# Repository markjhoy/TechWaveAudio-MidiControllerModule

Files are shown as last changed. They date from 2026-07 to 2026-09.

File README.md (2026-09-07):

# [TechWave Audio MIDI to CV Module](https://techwaveaudio.com/techwave-audio-mcm-100-midi-to-cv-eurorack-module/) : MCM-100

A monophonic MIDI controller Eurorack module using the Raspberry Pi Pico (RP2040).

Brought to you by [TechWave Audio](https://techwaveaudio.com)

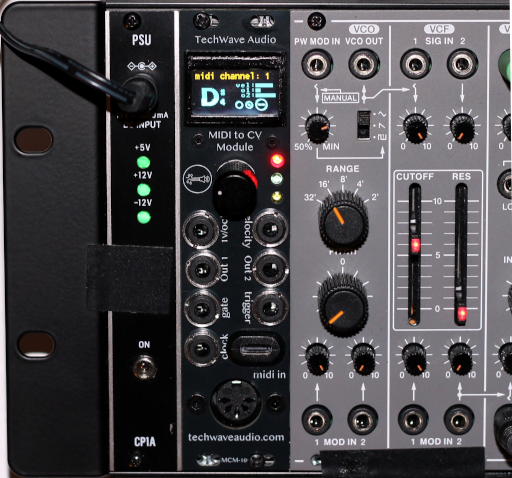
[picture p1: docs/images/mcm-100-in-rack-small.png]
TechWave Audio Midi Controller Module


## Features
* Single or omni MIDI channel input
* MIDI input via class-compliant USB-C or standard 5-pin MIDI cable
* Four CV outputs for note (1v/oct), Velocity, assignable Out 1 and Out 2 
  * 1v/octave through 10 octaves (at 0 to +10v), or 5 octaves (at 0 to +5v)
  * Two CV outputs with flexible routing
  * All CV outputs voltage selectable from 0v to +10v or 0 to +5v
* Expandable with additional four flexible-routed CV outputs.
* Gate, trigger, and clock full 0 to +5v outputs with divisible clock sync ticks
* Selectable note priority (last, highest, lowest)
* Tuneable pitch and velocity adjust
* Customizable trigger output duration pulse width
* Pitch bend response range from 0 to 5 octaves
* Real time display of note and output states
* Settings persist to on-board flash ROM
* 6hp wide, 3U height
* Max Power Draw:
  * +12v: 72mA (80mA with expansion) 
  * -12v: 15mA (20mA with expansion)
  * +5v: 0mA

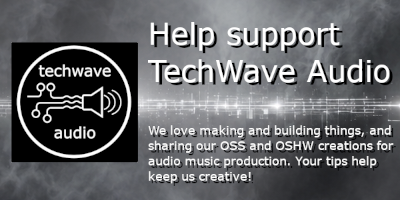
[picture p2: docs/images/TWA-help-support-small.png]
Help support our work!
[](https://ko-fi.com/techwaveaudio)

---

### Responds to the following MIDI messages:

* **Note on / off**: sends/stops the note and velocity outputs.
  * Sends a trigger pulse on note on, and turns on the gate for the duration of the note.
  * For +10v output, responds to C-1 (note number 0) to B9 (note number 119).
  * For +5v output, responds to C2 (middle-C, note number 36) to B6 (note number 95).
* **Volume**: increases or decreases the velocity output.
* **Pitch bend**: modifies any currently playing note. Adjustable range from 0 to 5 octaves. 
* **Sustain**: holds a note on while the sustain is active.
* **Aftertouch**: selectable as an aux and/or control output.
* **Expression**: selectable as an aux and/or control output.
* **Mod wheel**: selectable as an aux and/or control output.
* **Effect 1**: selectable as an aux and/or control output.
* **Effect 2**: selectable as an aux and/or control output.
* **Start** and **Continue** sequence: selectable as an aux and/or control output.
* **Stop** sequence: selectable as an aux and/or control output.
* **Mute** (all notes off): clears any note, velocity, and gate outputs.
* **Clock tick**: MIDI clock ticks are sent directly to the `Clock` output and can be routed as an aux and/or control output.
* **Reset**: reset the MIDI input messaging queue and stops any output.

---

### Inputs

* **MIDI in**: single channel or respond to all channels (omni)
  * Both MIDI via UART and USB MIDI device in (as of v1.2.0) 
* **Menu navigation**: Five way switch (up/down, left/right, push enter)

--- 
### Outputs

* Four CV outputs:
  * **Note**: 0 to 10v output (selectable to 0 to 5v) for CV with 1v per octave.
  * **Velocity**: 0 to 10v output (selectable to 0 to 5v) for velocity / volume
  * **Out 1**: customizable CV output (0v to +10v max, selectable to 0v to +5v)
  * **Out 2**: customizable CV output (0v to +10v max, selectable to 0v to +5v)
* **Trigger**: single pulse when a note turns on, with customizable pulse on time (high / low level output)
* **Gate**: signal goes high while a note is on (high / low level output)
* **Clock**: 1ms pulse with each MIDI clock tick (high / low level output). Selectable to various clock divisions.

Using the MCM-100-EX Expansion Module, you can also add an additional four assignable CV outputs.

---

### Power

This module requires a full 16 pin (2x08 connector) standard Eurorack power connection as it uses both +/- 12v lines as well as the +5v source. 
Optional selectors in the hardware (via a DIP switch) allow the note signal to pass through to the CV bus line, and the gate signal as well.

Be certain when you plug the connector in that the orientation is the correct way, with the -12v line on the bottom (usually with the red stripe).

---

## Usage

On startup, you should see the boot screen with the current version:

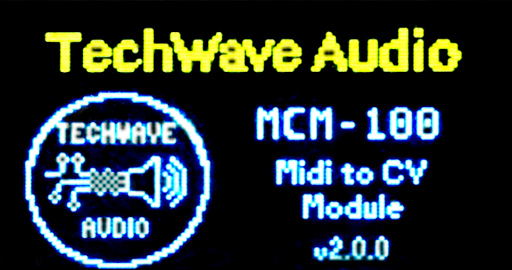
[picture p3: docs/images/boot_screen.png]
starting boot screen


The note and clock LEDs should turn on and off a few times before the dashboard screen is shown and the module is ready to be used.

The user manual can be found on the [TechWave Audio website](https://techwaveaudio.com/support/manuals/MCM-100-User_Manual.pdf).

### Dashboard

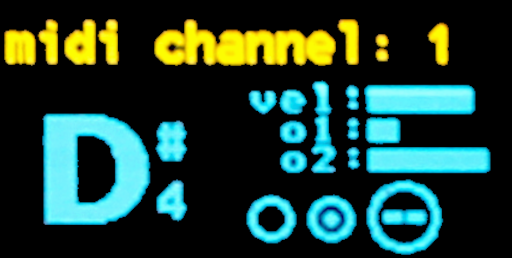
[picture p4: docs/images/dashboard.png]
main dashboard display


The dashboard shows the status of the current MIDI channel that it is listening on, as well as various outputs:
* The note and octave
* `vel`: The current velocity (corresponding to 0v to +10/+5v)
* `o1`: The current Out 1 value (corresponding to 0v to +10/+5v)
* `o2`: The current Out 2 value (corresponding to 0v to +10/+5v)
* Indicators for the state of the trigger, gate, and clock

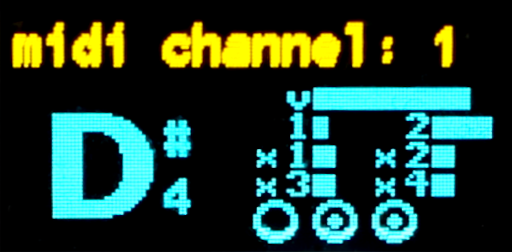
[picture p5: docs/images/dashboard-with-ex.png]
dashboard with expansion


If the MCM-100-EX expansion module is attached, additionally it will show:
* `x1`: The current Out X1 value (corresponding to 0v to +10/+5v)
* `x2`: The current Out X2 value (corresponding to 0v to +10/+5v)
* `x3`: The current Out X3 value (corresponding to 0v to +10/+5v)
* `x4`: The current Out X4 value (corresponding to 0v to +10/+5v)

While using the module, you can turn the dashboard display on and off via the display settings menu.
You can also adjust how often the display refreshes (set to a longer time if display events start to get dropped, shorter time for more frequent updates).

### Settings Menu

There are numerous settings available from the settings menu.
Pressing the encoder button on the dashboard display (regardless if the display is visible or not) will enter the menu.
See the [Menu System](./docs/MENU_SYSTEM.md) documentation for the menu system details.

**Note**: any settings are not persisted until you exit the menu back to the dashboard (with the exception of when resetting the settings to default).

## Building the Firmware From Source

### Prerequisites

* [Raspberry Pi Pico SDK](https://github.com/raspberrypi/pico-sdk)
* CMake
* Your favourite C++ compiler
* A compatible toolchain for building Pico firmware

### Setup

1. Initialize the Git submodules:
   1. run: `git submodule init`
   2. run: `git submodule update`
2. Copy the `.env.cmake.sample` to `.env.cmake`
3. Edit your `.env.cmake` for the following variables:
```
PICO_SDK_PATH {the path to the PICO_SDK directory)
PICO_TOOLCHAIN_PATH (path to the pico toolchain for your build machine)

# You should _not_ have to change the following
set(PICO_PLATFORM rp2040)
set(PICO_BOARD pico)
```

### Build script
```
./build.sh
```

This will run the full clean and build.

The firmware file will be put in:
```
./dist/TechWaveAudio-MCM-v2.0.0.uf2
```

## Firmware Updates

For this, you'll need a [firmware release](https://github.com/TechWave-Audio/TechWaveAudio-MidiControllerModule/releases) (or build your on locally), as well as a USB cable that has a micro-usb port on one end.

1.	Power off your rack.
2.	Remove the module from your rack but keep the module plugged in via the power cable.
3.	Download the desired firmware file version from the GitHub repository [firmware release](https://github.com/TechWave-Audio/TechWaveAudio-MidiControllerModule/releases). You only need to download the file with the .uf2 extension.
4.	Plug your USB-C cable into the jack on the front of the module and the other end into the computer with the firmware.
5.	While holding down the small boot select (BOOTSEL) button on the board, power on the module. Keep holding the boot select button until the module appears on your computer. The on-board Raspberry Pi Pico board will appear as a mass storage device, usually named “RPI-RP2”
6.	Copy the downloaded firmware .uf2 file to the storage device. When complete, the module should reboot.
7.	Power off your rack again.
8.	Disconnect your USB cable from the module and your computer. Your computer may give you a warning about the device not being properly ejected. You can safely ignore this warning.
9.	Put the module back into your rack and power back on.

Note that any settings you many have modified will be reset to any default.

## Design

## Schematic, PCB, and hardware

See the [hardware design](./docs/HARDWARE_DESIGN.md) documentation for information on the schematic and PCB design for the module.

Note - all files provided including KiCad designs and any gerber files are provided as-is and to be used at your own risk.
TechWave Audio does not guarantee the accuracy or any correctness of these files.
See the [HW_LICENSE license file](./HW_LICENSE.txt) for more, specifically the section "6 DISCLAIMER AND LIABILITY".

## Licensing

Software in this repository is licensed under the [BSD-3 License](LICENSE.txt). By using or contributing content to this repository you are agreeing to place your contributions under this license.

Hardware designs for this repository are [licensed under the CERN-OHL-S](HW_LICENSE.txt) ([CERN Open Hardware License](https://cern-ohl.web.cern.ch/)).

Parts of this repository may reference, depend on, or use compiled third party libraries. See [NOTICE.txt](NOTICE.txt) for additional details.

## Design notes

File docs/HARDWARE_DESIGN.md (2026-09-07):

# TechWave Audio Midi Controller Module Hardware Design

Simply put, the module reads MIDI messages in, and outputs signals to digital analog controllers to provide the voltage outputs.
This is all based around a RP2040 microcontroller as the brains for handling inputs and outputs.

* [Main Board](#main-board)
  * [Microcontroller](#microcontroller)
  * [MIDI Input](#midi-input)
  * [Note, Velocity, and Out 1 and 2 DAC](#note-velocity-and-out-1-and-2-dac)
  * [Encoder Button Debounce](#encoder-button-debouncing)
  * [Power](#power)
  * [Expansion Header](#expansion-header)

* [I/O Board](#io-board)
  * [Note, Velocity, Out 1 and 2 Outputs](#note-velocity-out-1-and-2-outputs)
  * [Gate, Trigger, and Clock Output](#gate-trigger-and-clock-output)
  * [Rotary Encoder User Input](#rotary-encoder-user-input)
  * [OLED Screen](#oled-screen)
  
* [MCM-100-EX Expansion Module](#mcm-100-ex-expansion-module)

* [MCM-100 Parts List / BOM](#mcm-100-parts-list)
* [MCM-100-EX Parts List / BOM](#mcm-100-ex-parts-list)
* [Board Renderings](#board-renderings)

# Main Board

The main board (lower PCB) houses the RP2040 Raspberry Pi Pico microcontroller, MIDI input, the note, velocity, and out 1 and 2 DAC, and power handling. 

## Microcontroller
The microcontroller at the heart of the system is a RP2040 based [Raspberry Pi Pico 1](https://www.raspberrypi.com/documentation/microcontrollers/pico-series.html#pico1).
The RP2040 is a very capable and low cost with enough GPIO, I2C, and SPI lines to handle the needs of this system.

To keep the design a bit more accessible, I made the conscience decision to use the Raspberry Pi Pico module itself instead of opting for using a discrete RP2040 chip only.
Using a discrete RP2040 itself would have allowed for a much smaller footprint on the PCB, however the using the full module allowed for easier testing overall without having to worry about getting the microcontroller section of the circuitry right (why reinvent the wheel).
It also makes flashing the firmware much easier (although I could have added a discrete USB port for doing so).

Both cores of the RP2040 are used. Core 0 handles the display, buttons, menus, and state. 
Core 1 handles the MIDI input and hardware outputs.

## MIDI Input

The MIDI input from the 5-pin DIN MIDI cable jack is handled by a 6N137 optocoupler that signals at +5v.
The output signal is reduced to +3.3v via a simple voltage divider to bring the signal to a manageable level for the microcontroller to use.
COnversely, the USB-C jack is soldered directly into the data + and -, and the ground for the USB on the Pi Pico.
All processing of the signal happens within the software.

## Note, Velocity, and Out 1 and 2 DAC

The module uses a DAC7554 quad 12-bit SPI digital to analog IC for its CV output.
The Pi Pico communicates with the IC, and the resulting 0 to +5v signal is passed to the I/O board where the op amps provide additional gain and trimming.

## Encoder Button Debouncing

On the main board as well, there is a small circuit consisting of several filtering capacitors and resistors along with a NPN transistor that acts as a light hardware debounce for the rotary encoder button.
This arrangements provides for approximately a 40ms debounce of the encoder button.

## Power

The power coupling for the module uses a standard 10 pin (2x05) IDC connector as detailed in the original [A-100 Doepfer power system bus](https://doepfer.de/a100_man/a100t_e.htm).

There are a pair of schottky diodes for reverse power protection as well as several capacitors for power filtering.
A 7805 equivalent power regulator is used to drop the +12v line down to +5v for input to the microcontroller, DAC, optocoupler, and encoder button debouncing.

As measured, the maximum power draw is:
* +12v: 72mA (80mA with expansion)
* -12v: 15mA (20mA with expansion)
* +5v: 0mA

## Expansion Header

The expansion header is a 2x05 set of pin headers that the MCM-100-EX expansion cable attaches to.
The headers carry +12v/-12v/+5v power as well as SPI lines for communicating with the DAC on the expansion board.

# I/O Board

The upper I/O board contains the output jacks, the screen, rotary encoder as well as op amp gain and trimmer 

## Note, Velocity, Out 1 and 2 Outputs

The note 1v/oct and velocity signals are handled by two MCP4725 DAC ICs.
These are single channel, 12 bit DAC chips that use I2C for communication from the microcontroller.
Since these chips are able to output between 0 and +5v, the signal is then increased to the 0 to +10v range via a TL074 opamp.
Additional 1k trimming potentiometers are used to fine tune the output.

The control and aux signals are handled by a single MCP4902 DAC IC.
This is a single channel 8 bit DAC chip that uses SPI for communication with the microcontroller.
This chip produces a stable output voltage from 0 to +5v, which in turns is sent through a TL074 op amp to increase the range to 0 to +10v.
Like the note and velocity outputs, there are 1k trim potentiometers to fine tune the output voltages.

## Gate, Trigger, and Clock Output

The gate, trigger and clock signals all run directly from the associated GPIO pins from the microcontroller.
Because these signals coming out of the Pi Pico are at 3.3v, a TL074 op amp is used to turn the pulses into 0 to +5v signals.

## Rotary Encoder User Input

The rotary encoder is a standard EC11 rotary encoder.
To attach the rotary encoder to the I/O board, a custom mid-board was created.
See [the design files for the custom board](../design/RotaryEncoderCarrierBoard) in the design folder.

## OLED Screen

The OLED screen used is a 0.96" display using the SSD1306 chipset.
These modules can be found at a reasonable price, and offer enough performance for the needs of this module.
Communication with the microcontroller is via an I2C bus.

# MCM-100-EX Expansion Module

The MCM-100-EX expansion module consists of a DAC7554 quad 12-bit digital to analog converter as the main CV controller for the expansion.
Each of the outputs feeds into a TL072 op amp for additional gain before being sent to the audio jacks.
There is no external power, but rather the expansion module receives power (+12v, -12v, and +5v) from the MCM-100 via the attachment cable.
In addition, there is also a small 1k resistor that is used to read from the Pi Pico to sense the expansion is attached.

# MCM-100 Main Board Parts List

## Surface Mount Components

| ID | Qty | Description | Package |
|---|-----|---|---|
| C1-C5 | 5 | 10uF Capacitor Tantalum 6032-28 | 6032 |
| C6-C10, C21  | 6 | 100nf Capacitor | 0402 |
|C11| 1 | 10uF Capacitor | 8085 |
|C12, C13 | 2 | 10nf Capacitor | 0402 |
|C14 | 1 | 330nf Capacitor | 0402 |
|D1, D2, D4 | 3	| Schottky	Diode | 0805 |
|D3, D8 | 2	| 1N4148 Diode | SOD-323 |
|Q1 | 1 | MMBT3904 |SOT-23|
|R14, R16 | 2 | 4.7k Resistor|0402
|R15, R17-R19, R21, R40 | 6	| 10k Resistor | 0402
|R20, R22-R24 | 4 | 100k Resistor | 0402
|R25 | 1 | 330k Resistor | 0402
|R28 | 1 | 220 Resistor | 0402
|R33 | 1 | 1k Resistor | 0402
|R39 | 1 | 5.1k Resistor | 0402
|R41 | 1 | 47k Resistor | 0402
|U1 | 1 | L7805 | SOT-223-3
|U3 | 1 | DAC7554IDGSR | TSSOP-10

## Through Hole Components

| ID  | Qty | Description 
|-----|---|---
| A1  | 1 | Raspberry Pi Pico 
| J1  | 1 | 10 pos 2x05 IDC socket
| J16 | 1 | 1x08 pin socket
| J17 | 1 | 2x04 pin socket
| J18 |	1 | 2x03 pin socket
| J20 | 1 | 2x05 pin header for expansion
| U2 | 1 | 6N137 Optocoupler

# MCM-100 I/O Board Parts List

## Surface Mount Components

| ID | Qty | Description | Package 
|---|-----|---|-
| R2, R5, R31, R32 | 4 | 4.7k Resistor | 0402
| R4, R6-R9, R29, R30 | 7 | 5.1k Resistor | 0402
R10-R12 | 3 | 10k Resistor | 0402
R13, R16, R36 | 3 | 1k Resistor | 0402
R37, R38 | 2 | 330 Resistor | 0402
U1, U2 | 2 | TL074 | SOIC-14

# Through Hole Components

| ID  | Qty | Description 
|-----|-|-
| D9 | 1 | 3mm red LED for Power
| D10 | 1 | 3mm yellow LED for Clock 
| D1 | 1 | 3mm green LED for Note 
| J2-J6, J13, J14 | 7 | 3.5mm Jack, vertical
| J9  | 1 | 2x04 pin header 
| J15 | 1 | 1x08 pin header 
| J19 | 1 | 2x03 pin header 
| OLED1 | 1	| SSD1306 i2c OLED module, 4 pin interface
| R1, R3, R34, R35 | 4 | 1k	trimmer potentiometer 
| SW1 | 1 | EC11 Encoder Switch with Push Button (on carrier board)

# MCM-100-EX Parts List

## Surface Mount components

| ID  | Qty | Description
|-|-|--
| C1 | 1 |100nf	Capacitor SMD 0402 
| C2 | 1 |10uF Capacitor 0805 |	| | https://cdn.sparkfun.com/assets/8/a/4/a/5/Kemet_Capacitor_Datasheet.pdf  
| R25,R26 | 2 | 1k Resistor SMD 0402
| R41-R48 | 8 | 51k	Resistor SMD 0402
| U1 | 1 | DAC7554 MSOP-10 | | | http://www.ti.com/lit/gpn/DAC7554
| U2,U3 | 2 | TL072 SOIC-8 | | | http://www.ti.com/lit/ds/symlink/tl071.pdf

## Through Hole Components

| ID  | Qty | Description
|-----|---|---
| D1  | 1 | 3.0mm red LED	 |
| J21 |1 | 10p 2x05 IDC Docket  |
| J22-J25 | 4 | 3.5mm Jack, vertical

# Board Renderings
## Main Board Rendering
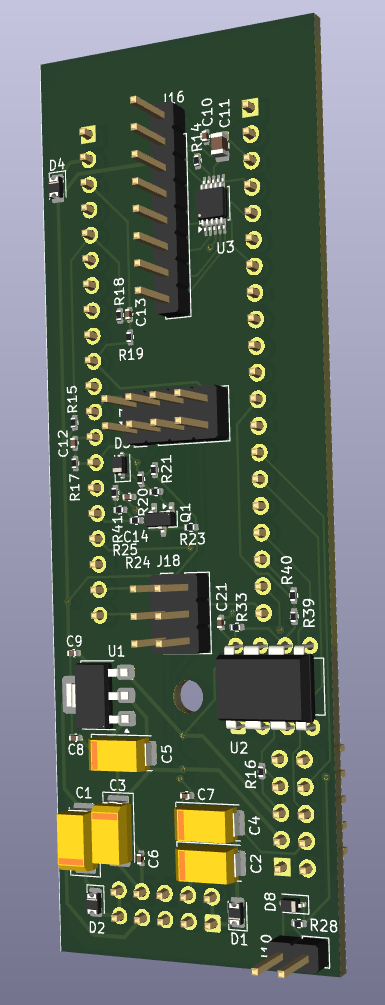
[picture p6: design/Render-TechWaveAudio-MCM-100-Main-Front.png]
Rendered I/O board


## I/O Board Rendering

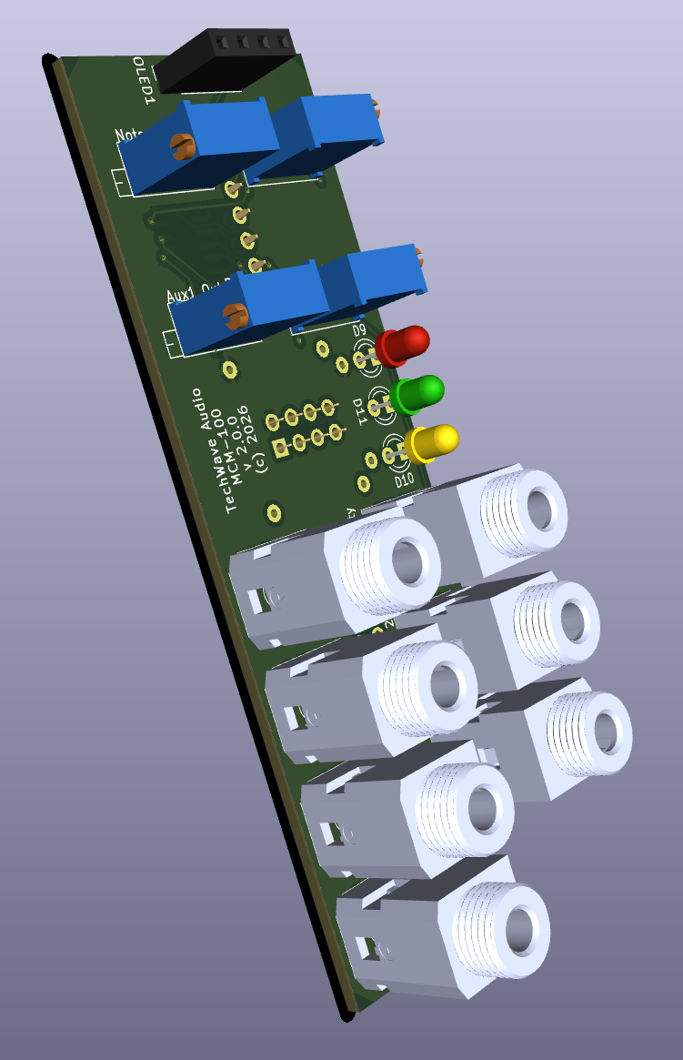
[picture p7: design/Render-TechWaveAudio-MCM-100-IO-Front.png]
Rendered main board


## Main PCB Layout
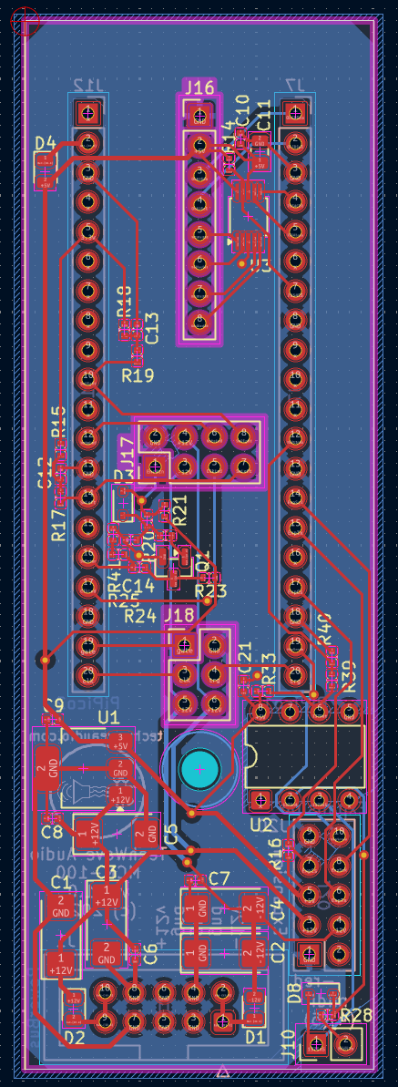
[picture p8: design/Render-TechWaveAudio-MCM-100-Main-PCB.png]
Main PCB layout


## I/O PCB Layout
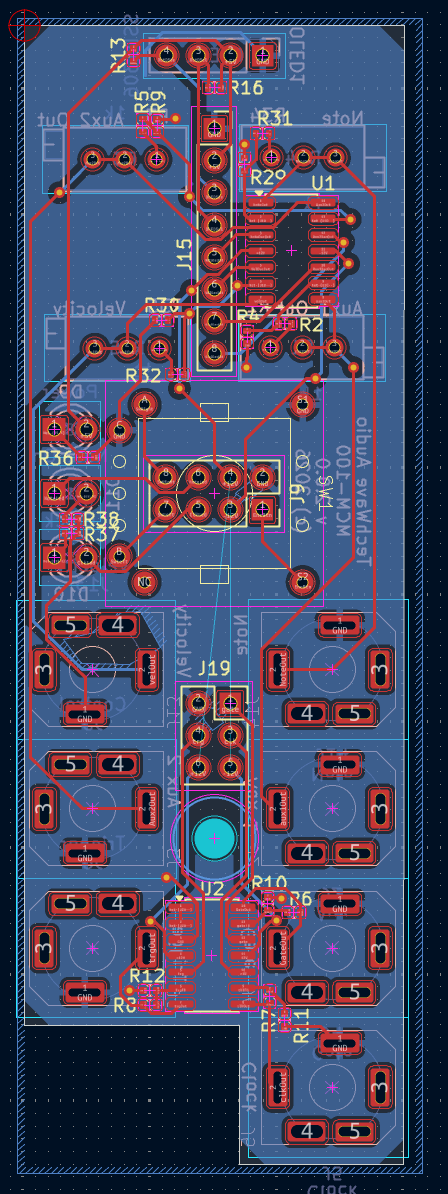
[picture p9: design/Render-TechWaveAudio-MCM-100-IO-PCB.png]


## Expansion Board Rendering
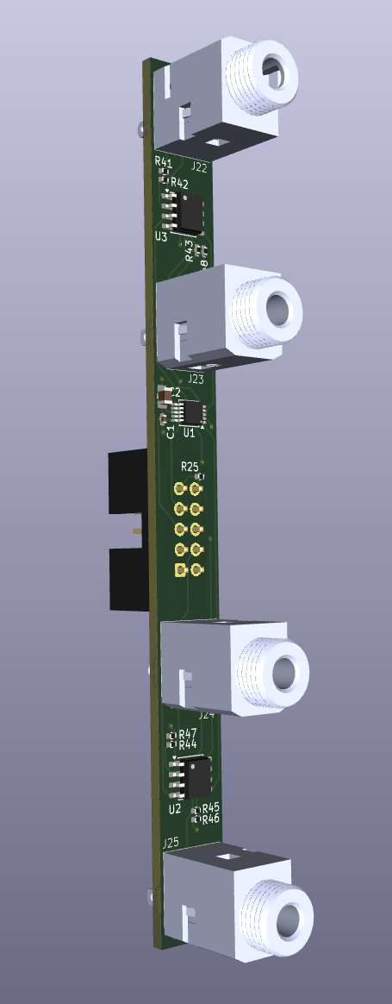
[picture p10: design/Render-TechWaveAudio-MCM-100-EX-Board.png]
Rendered expansion board


## Expansion PCB Layout
IO PCB layout

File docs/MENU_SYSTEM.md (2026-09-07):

# MIDI Controller Module Settings Menu System

## Menu System and Settings
To enter the menu system from the dashboard, press down (enter) on the rotary encoder knob.

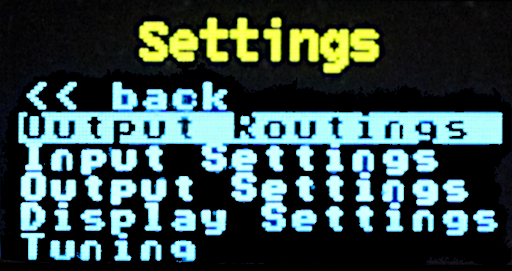
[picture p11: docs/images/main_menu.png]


In the setting main menu screen, use the rotary encoder knob to highlight the menu item you want, and press the button to select that item. From any screen, select and press button on the << back menu entry to return to the previous screen (or to the dashboard if on the main settings menu screen).
Any changes made within the settings menu will take effect immediately (i.e. a MIDI channel change). Note that no settings are persisted until you exit back to the dashboard, with the exception when you reset the settings to the defaults.

* [Output Routings](#output-routings)
* [Input Settings](#input-settings)
* [Midi channel settings](#midi-channel-settings)
* [Note Priority Settings](#note-priority-settings)
* [Output Settings](#output-settings)
* [Note Output Settings](#note-output-settings)
* [Pitch Adjustment Settings](#pitch-adjustment-settings)
* [Pitch Bend Range Settings](#pitch-bend-range-settings)
* [Velocity Output](#velocity-output)
* [Velocity Adjustment Settings](#velocity-adjustment-settings)
* [Assignable Output Settings](#assignable-output-settings)
* [Expansion CV Outputs](#expansion-cv-outputs)
* [Trigger Duration Settings](#trigger-duration-settings)
* [Clock Division Settings](#clock-division-settings)
* [Display Settings](#display-settings)
* [Tuning Menu](#tuning-menu)
* [About](#about)
* [Reset Settings](#reset-settings)

## Output Routings

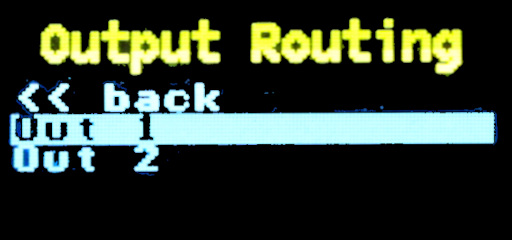
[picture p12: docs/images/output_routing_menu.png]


You can use the output routings menu to quickly select how to route incoming MIDI events to the Out 1 and Out 2 CV outputs (and to the X1, X2, X3 and X4 outputs if you have the expansion module attached).
Use the rotary encoder to highlight the output you wish to change the routing for and press the button down to enter the selection menu for that output.

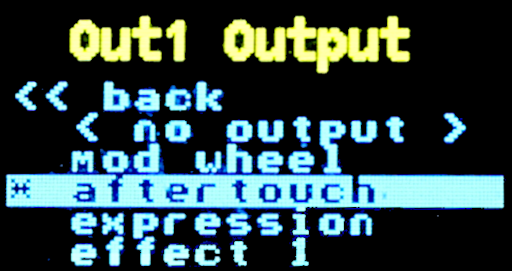
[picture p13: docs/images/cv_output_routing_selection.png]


When selecting the routing for an output, use the encoder knob to highlight the event you want the output route to map to and press the encoder button to select it. The currently selected output route will have a star next to it (*). Only one event type can be routed to each of the outputs, however, you can assign the same event type to any of them. When finished, use the rotary encoder knob to highlight and select the << back menu entry.
The events that are available to map are:
* None: (do not route anything to the output)
* Aftertouch: CV output. Channel only, no poly aftertouch
* Expression: CV output. CC message 0x0B
* Mod Wheel: CV output. CC message 0x01
* Effect 1: CV output. CC message 0x0C
* Effect 2: CV output. CC message 0x0D
* Gate: signal output. +5v signal when the gate is active
* Trigger: pulse output. +5v signal pulse when a note is triggered
* Run and Continue: signal output responding to Start (sys message 0xFA) and Continue (0xFB). The output will be a +5v signal held high, only turned off by a reset or reset all event.
* Reset: pulse output. Sys message 0xFC, Stop (+5v signal pulse)
* Note: CV output. MIDI note number when there is a note on event
* Velocity: CV output. velocity value when there is a note on event
* Clock ticks: pulse output. +5v pulse when a clock sync is received (sys message 0xF8). The clock ticks are configurable to pulse with every tick, or every 2, 4, 6, 8, 12, 24, 36, 48, 60, 72, or 96 ticks.

## Input Settings
Through the input settings menu, you can set the midi channel and the input note priority settings.

## Midi channel settings
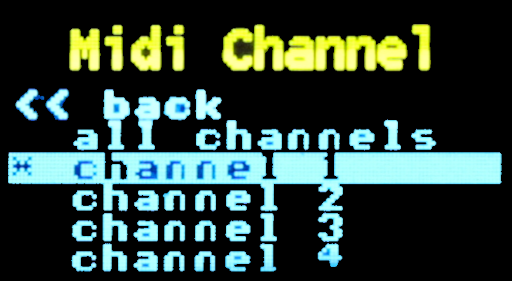
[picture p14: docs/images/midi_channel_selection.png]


Set the MIDI channel to listen for incoming events on. You can select from channels 1 through 16, as well as (all channels).
Use the rotary encoder to select the channel setting and press the button to change the channel to listen on. The current setting with have a star next to it (*). Select the << back entry to go back to the main menu.

## Note Priority Settings
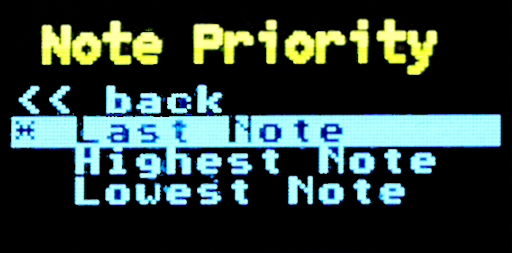
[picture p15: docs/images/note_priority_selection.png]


Sets the note priority for incoming note on events.
The available selections are:
* Last Note: The last incoming note event
* Highest Note: Only the highest note events are kept
* Lowest Note: Only the lowest note events are kept

Use the rotary encoder to select the note priority setting and press the encoder button to change it. The current setting with have a star next to it (*). Select the << back menu selection to go back to the input settings menu.

## Output Settings

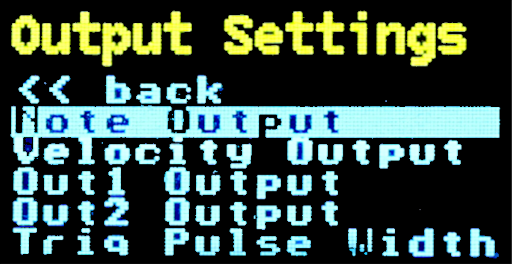
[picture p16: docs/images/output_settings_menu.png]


In the output settings menu, select the output you want to configure. For each of the CV outputs - note, velocity, Out 1, Out 2 (and additionally X1, X2, X3, and X4 if the expansion module is attached) - the output can be configured to a maximum CV output of +10 volts or +5 volts. All signal or pulse outputs are always at +5 volts. Here you can also adjust the pulse width of the trigger event as well as the clock output settings.
For the note output, at +10 volts maximum output, the note on events respond to notes C-1 (note number 0) to B9 (note number 119). For +5 volts output, note on events respond to notes C2 (middle-C, note number 36) to B6 (note number 95).

## Note Output Settings
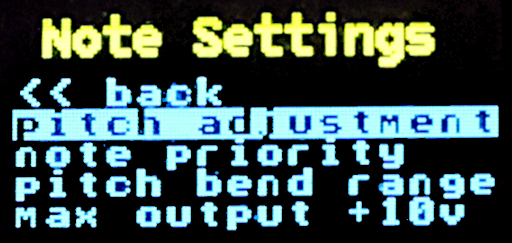
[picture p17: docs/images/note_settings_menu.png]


From the note output settings, you can adjust the pitch of the 1v/oct note output CV, the pitch bend range number of octaves, or the maximum voltage for the note CV output. To change the maximum voltage output, use the rotary encoder to highlight the menu item and press the encoder button to toggle between +10v and +5v. 

## Pitch Adjustment Settings

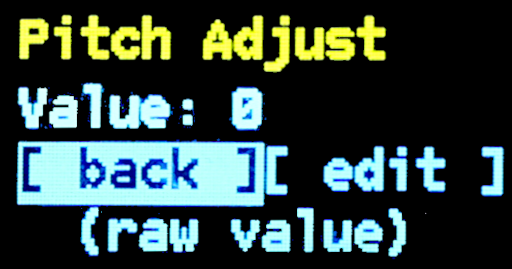
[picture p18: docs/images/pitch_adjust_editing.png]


Allows for adjustment of the outgoing CV value. The pitch adjustment allows for approximately +/- 6% output voltage (limited to 0 to +10/+5v). The adjustment slider ranges from -250.0 to 250.0 for the output value to the 12-bit DAC.

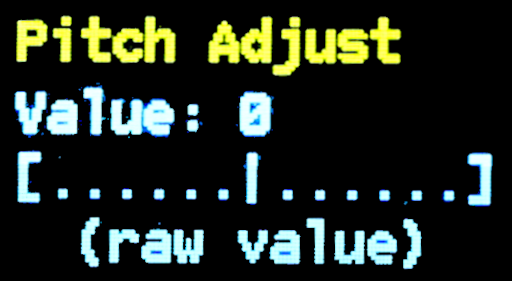
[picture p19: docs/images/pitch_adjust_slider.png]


Select the edit menu item with the encoder and press the encoder button to start editing the value. When editing the value, turn the rotary encoder left or right to change the value. Press the encoder button to set the value and go back. Select the back menu item to go back to the previous menu.

## Pitch Bend Range Settings
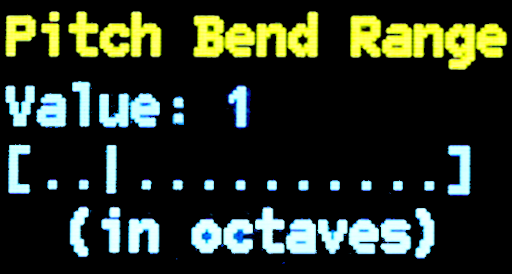
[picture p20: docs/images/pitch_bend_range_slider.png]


Sets the number of +/- octaves the pitch bend will cover from 0 to 5 octaves.
Select the [ edit ] menu item with the encoder and press the encoder button to start editing the value (in octaves or part of an octave). When editing the value, turn the rotary encoder left or right to change the value. Press the encoder button to set the value and go back. Select the [ back ] choice to go back to the previous menu.

## Velocity Output

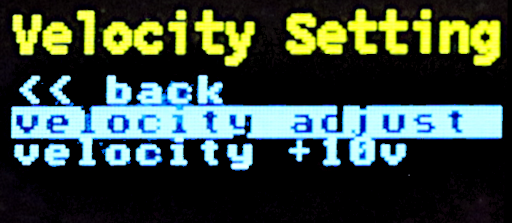
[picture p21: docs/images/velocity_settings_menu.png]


From the velocity output menu, you can choose to adjust the velocity output via the “velocity adjust” menu selection, or the maximum voltage output for the velocity CV output. To change the maximum voltage output, use the rotary encoder to highlight the menu item and press the encoder button to toggle between +10v and +5v.

## Velocity Adjustment Settings

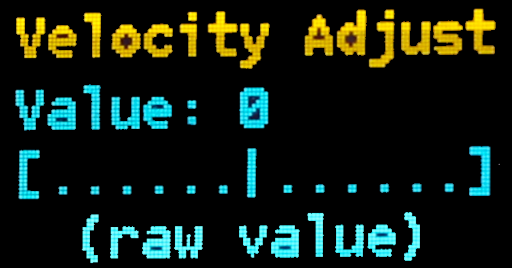
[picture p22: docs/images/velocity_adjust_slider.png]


Allows for adjustment of the outgoing velocity value. The velocity adjustment allows for approximately +/- 6% output voltage (limited to 0 to +10/+5v). The adjustment slider ranges from -250.0 to 250.0 for the output value to the 12-bit DAC.
Select the [ edit ] menu item with the encoder and press the encoder button to start editing the value. When editing the value, turn the rotary encoder left or right to change the value. Press the encoder button to set the value and go back. Select the [ back ] choice to go back to the previous menu.

## Assignable Output Settings

You can configure the output settings for Out 1 and Out 2. From this menu, you can choose the event routing for the selected CV output as well as output voltage (either +10v to +5v max).
To route a MIDI event to the output, select the route menu item selection to choose what event should be routed to the output. The currently selected event output will be indicated with a star ‘*’ next to it. See the “Output Routings” section above for the list of assignable routes.
To change the maximum voltage output, use the rotary encoder to highlight the menu item and press the encoder button to toggle between +10v and +5v.

### Expansion CV Outputs
If you have the MCM-100-EX Expansion Module attached, you will be able to change the settings for the X1, X2, X3, and X4 outputs in the same manner as Out 1 and Out 2. Much the same, these outputs can have a MIDI event routed to them and the maximum output change be changed between +10v and +5v.

## Trigger Duration Settings

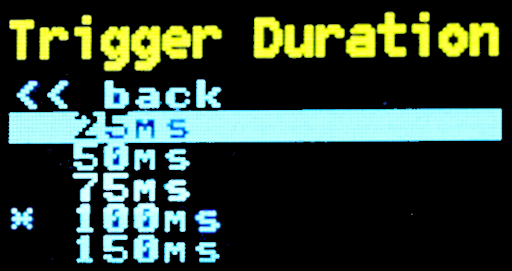
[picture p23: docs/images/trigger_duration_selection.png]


You can set how long the trigger pulse stays high when a note is turned on. The values range from 25 ms to 500 ms (default 100ms).
Use the rotary encoder to highlight the trigger duration and press the encoder button to select it. The current setting with have a star next to it (*). Select the << back menu option to go back to the previous menu.

## Clock Division Settings
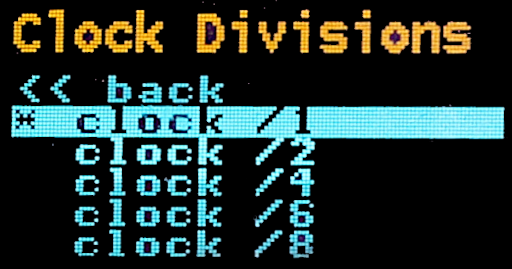
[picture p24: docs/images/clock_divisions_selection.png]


This menu allows you to set the output to the clock +5v pulse line. By default, every clock tick is sent as a pulse. In this menu, you can configure the system to send the pulse at other intervals including:
* every tick (24 times per frame)
* every 2 ticks (12 times per frame)
* every 4 ticks (6 times per frame)
* every 6 ticks (4 times per frame)
* every 8 ticks (3 times per frame)
* every 12 ticks (2 times per frame)
* every 24 ticks (once per frame)
* every 36 ticks (once every 1½ frames)
* every 48 ticks (once every two frames)
* every 60 ticks (once every two and ½ frames)
* every 72 ticks (once every three frames)
* every 96 ticks (once every four frames)

Use the rotary encoder to highlight the clock division setting you wish to use and press the encoder button to set it. The current setting with have a star next to it (*). Select the << back menu item to go back to the previous menu.

## Display Settings

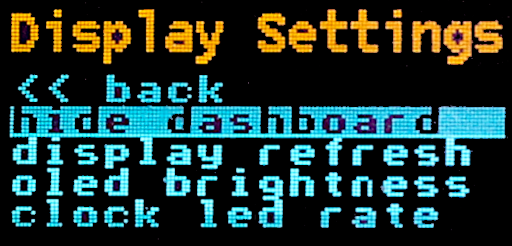
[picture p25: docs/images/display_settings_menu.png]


This menu allows you to modify the display settings for the dashboard and clock LED. The setting here include:
* Hide / show dashboard: keeps the dashboard display on or off when not in the menu. Highlight the menu item and press the encoder button to toggle hidden or showing.
* Dashboard refresh: sets the number of milliseconds for every refresh of the dashboard when displayed. Highlight the menu item and press the encoder button to go into the menu to choose the refresh rate. The current setting will have a star ‘*’ next to it.
* Display brightness: set the brightness of the display screen. To set the screen brightness, use the range editor to select a brightness level from 1 (dim) to 16 (most bright).
* Clock LED refresh: sets how often the clock LED blinks when receiving MIDI clock tick events.
  * off
  * every tick
  * every 2 ticks
  * every 3 ticks
  * every 6 ticks
  * every 12 ticks
  * every 24 ticks (full cycle)

Use the rotary encoder to select the setting to change and press the encoder button to select it. Select the << back entry to go back to the main menu.

## Tuning Menu
The tuning menu can be used to output a continuous voltage on the note CV output.
Use the rotary encoder to select the note to output and press the encoder button. The selected note voltage will be sent to the note CV output, and the gate line will turn on. You can then use an electronic tuner to adjust your VCO pitch, or alternatively an oscilloscope to view the frequency output from your mixer. The CV output will depend on the setting of the output voltage in the output voltage settings for the note output. Note that in the title area of the menu, the current max output voltage is displayed. Press the encoder button again to stop the output. Select the <<back menu item to go back to the main menu.

## About
Displays the current version and build information of the firmware. Press the encoder button to return to the main menu.

## Reset Settings
Allows you to reset the settings to their defaults. Use the rotary encoder to select the [confirm] reset item and press the encoder button to reset the module to the system default values. If you do not wish to reset the settings select the [ cancel ] item.
Note that if you do reset the settings, the default settings will immediately be saved over any custom configuration.
The default settings are:
* MIDI channel: 1
* Note priority: last note
* Pitch adjustment: 0.00
* Velocity adjustment: 0.00
* Pitch bend range: +/- 1 octave
* Out 1 route: aftertouch
* Out 2 route: mod wheel
* Trigger duration: 100 ms
* Clock divisions: every tick
* Note output max voltage: +10v
* Velocity output max voltage: +10v
* Out 1 output max voltage: +10v
* Out 2 output max voltage: +10v
* Dashboard display: on
* Dashboard refresh: every 25 ms
* Display brightness: 12 (about 75%)
* Clock LED: every 12 ticks

If you have the MCM-100-EX Expansion Module as well, all CV outputs X1, X2, X3, and X4 will all have their route set to “none”, and their max voltage set to +10v.

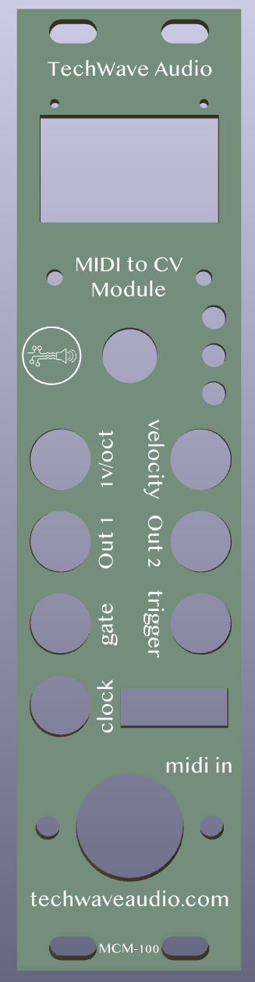
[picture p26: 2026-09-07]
design/Render-TechWaveAudio-MCM-100-Panel.png

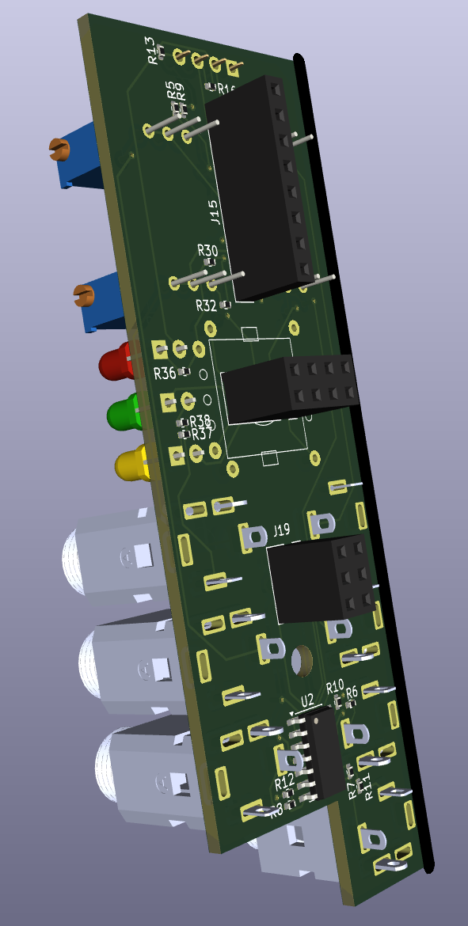
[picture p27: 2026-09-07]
design/Render-TechWaveAudio-MCM-100-IO-Rear.png

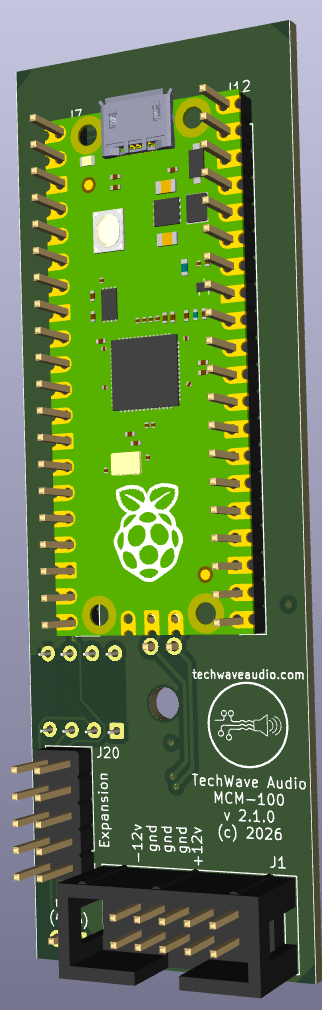
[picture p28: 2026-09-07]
design/Render-TechWaveAudio-MCM-100-Main-Rear.png

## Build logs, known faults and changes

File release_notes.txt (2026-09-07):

version 2.0.0 - September 7th, 2026

- Major version update
  - NOTE: Version 1.x hardware will _not_ work with this release. Use a version 1.x firmware release for updates.

- Totally revised hardware
- Now a 6hp module
- Using DAC7554 for DAC outputs
- Using a rotary encoder for input
- Split board design with a main PCB and an IO PCB
- Better signal handling on the board with better component layouts
- Able to add MCM-100-EX expansion module for four additional CV outputs

- Almost totally revised software
- Redesigned menu and dashboard system
- More responsive and better MIDI message handling.
- Fully routable CV outputs - send any event to any of the assignable CV outputs
- Clock divisions! Process every clock tick down to every 96 clock ticks (4 frames worth)
- Stability and optimization updates across the board

========--------========
version 1.3.1 - August 3rd, 2026

- fix bug where output controller signals for aux or control do not output correct +5v value if CV output is set to 5v

========--------========
version 1.3.0 - August 2nd, 2026

- new flexible routing options for aux and control CV outputs
- divisible clock output
- multi-note queue; if a note is held, and another is played, when that note goes off it will retrigger the previous
- midi sense capability
- updated dashboard
- updated menu system
- updated fonts

========--------========
version 1.2.0 - July 14th, 2026

- Added USB MIDI device capability

========--------========
version 1.1.0 - June 26th, 2026

- Initial public release

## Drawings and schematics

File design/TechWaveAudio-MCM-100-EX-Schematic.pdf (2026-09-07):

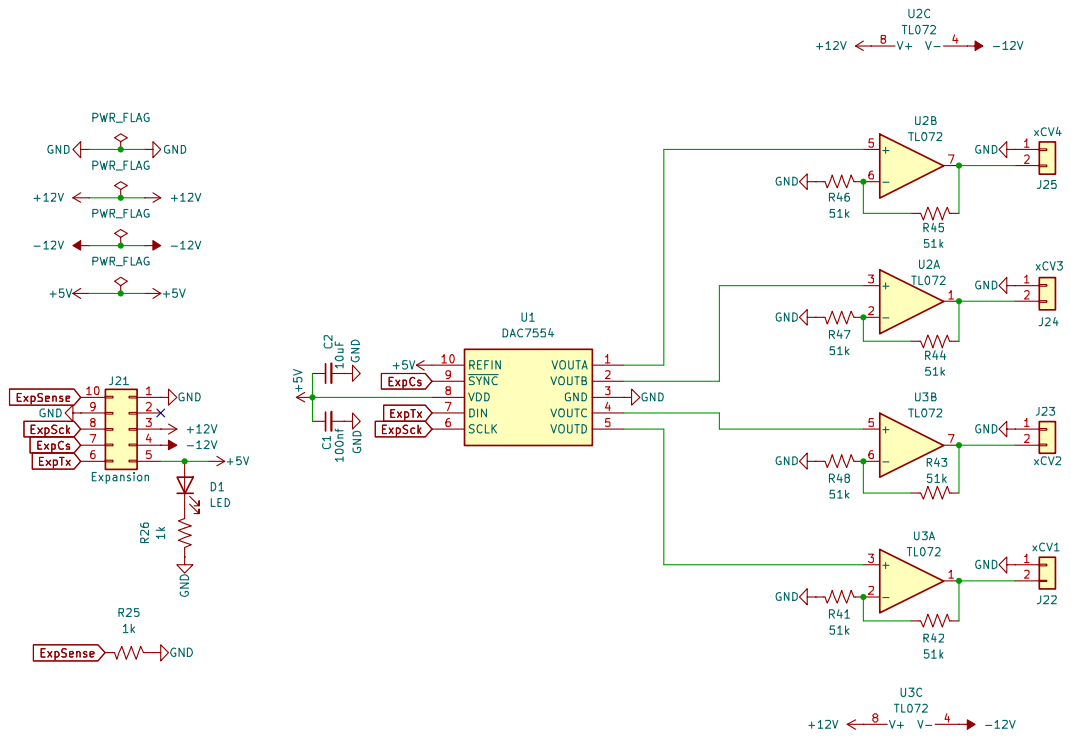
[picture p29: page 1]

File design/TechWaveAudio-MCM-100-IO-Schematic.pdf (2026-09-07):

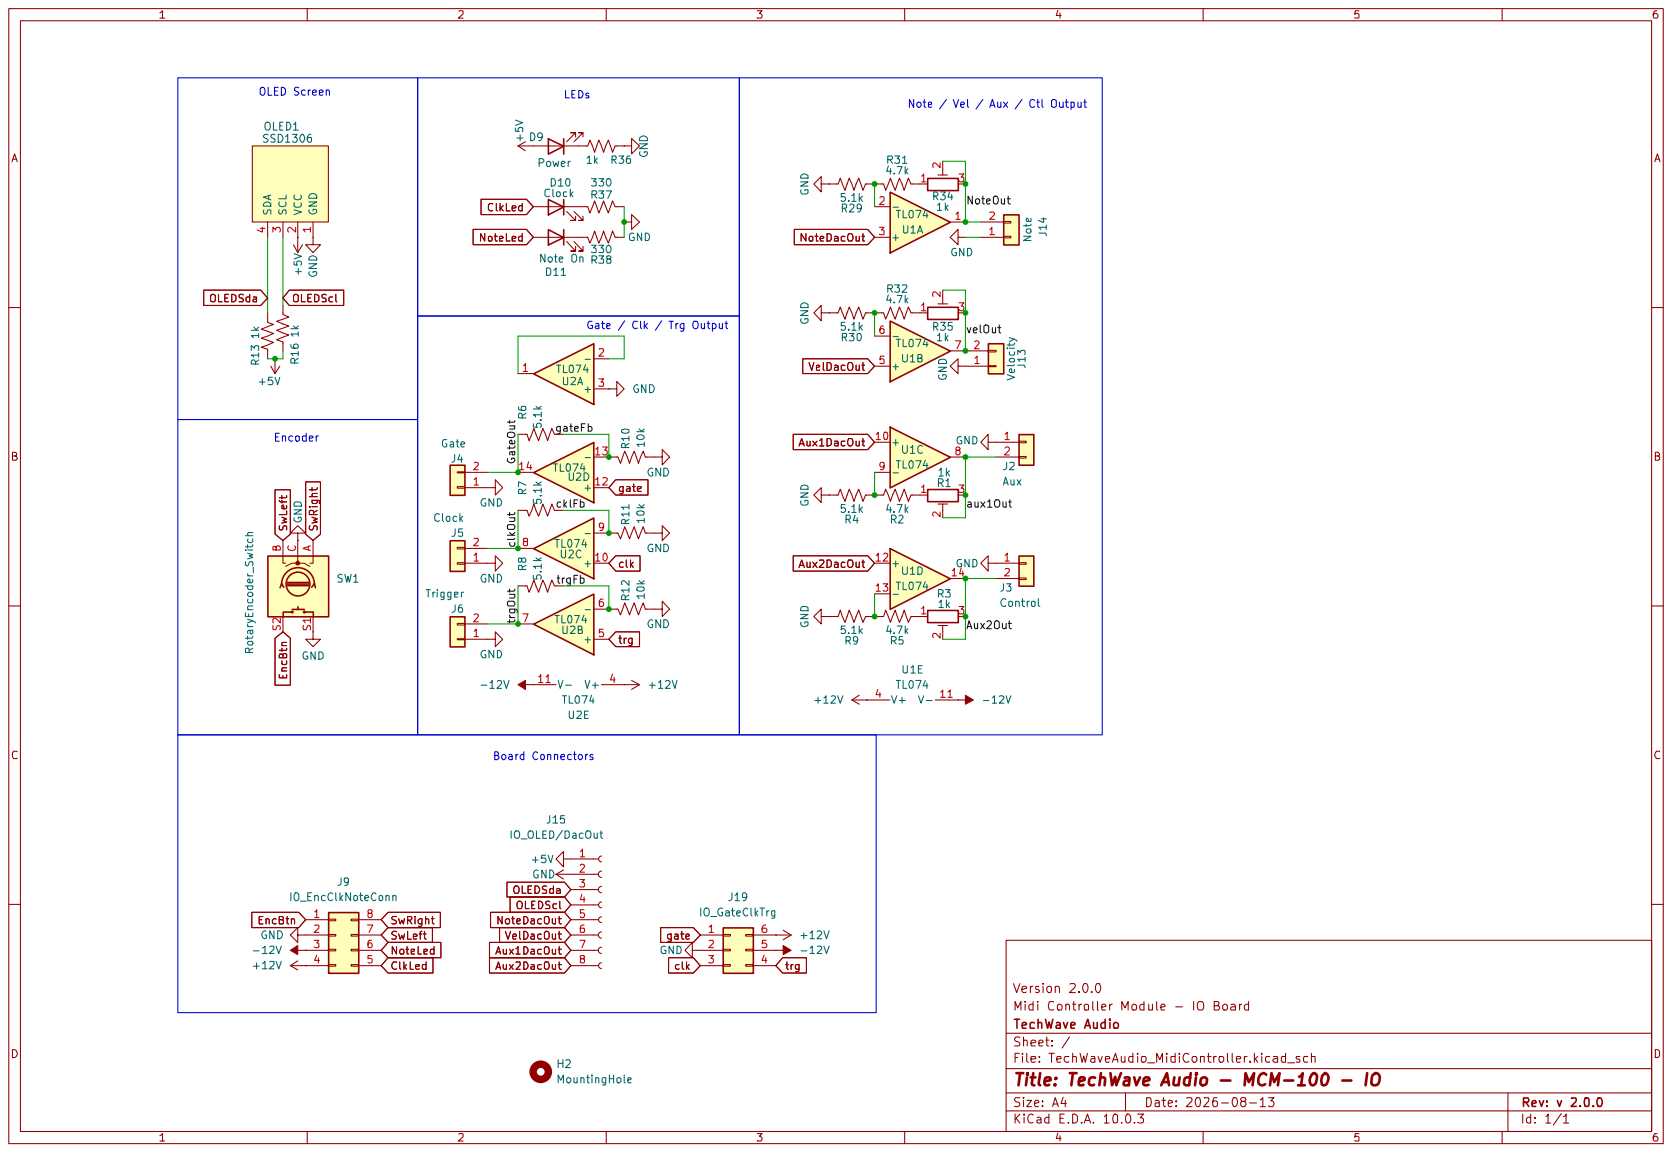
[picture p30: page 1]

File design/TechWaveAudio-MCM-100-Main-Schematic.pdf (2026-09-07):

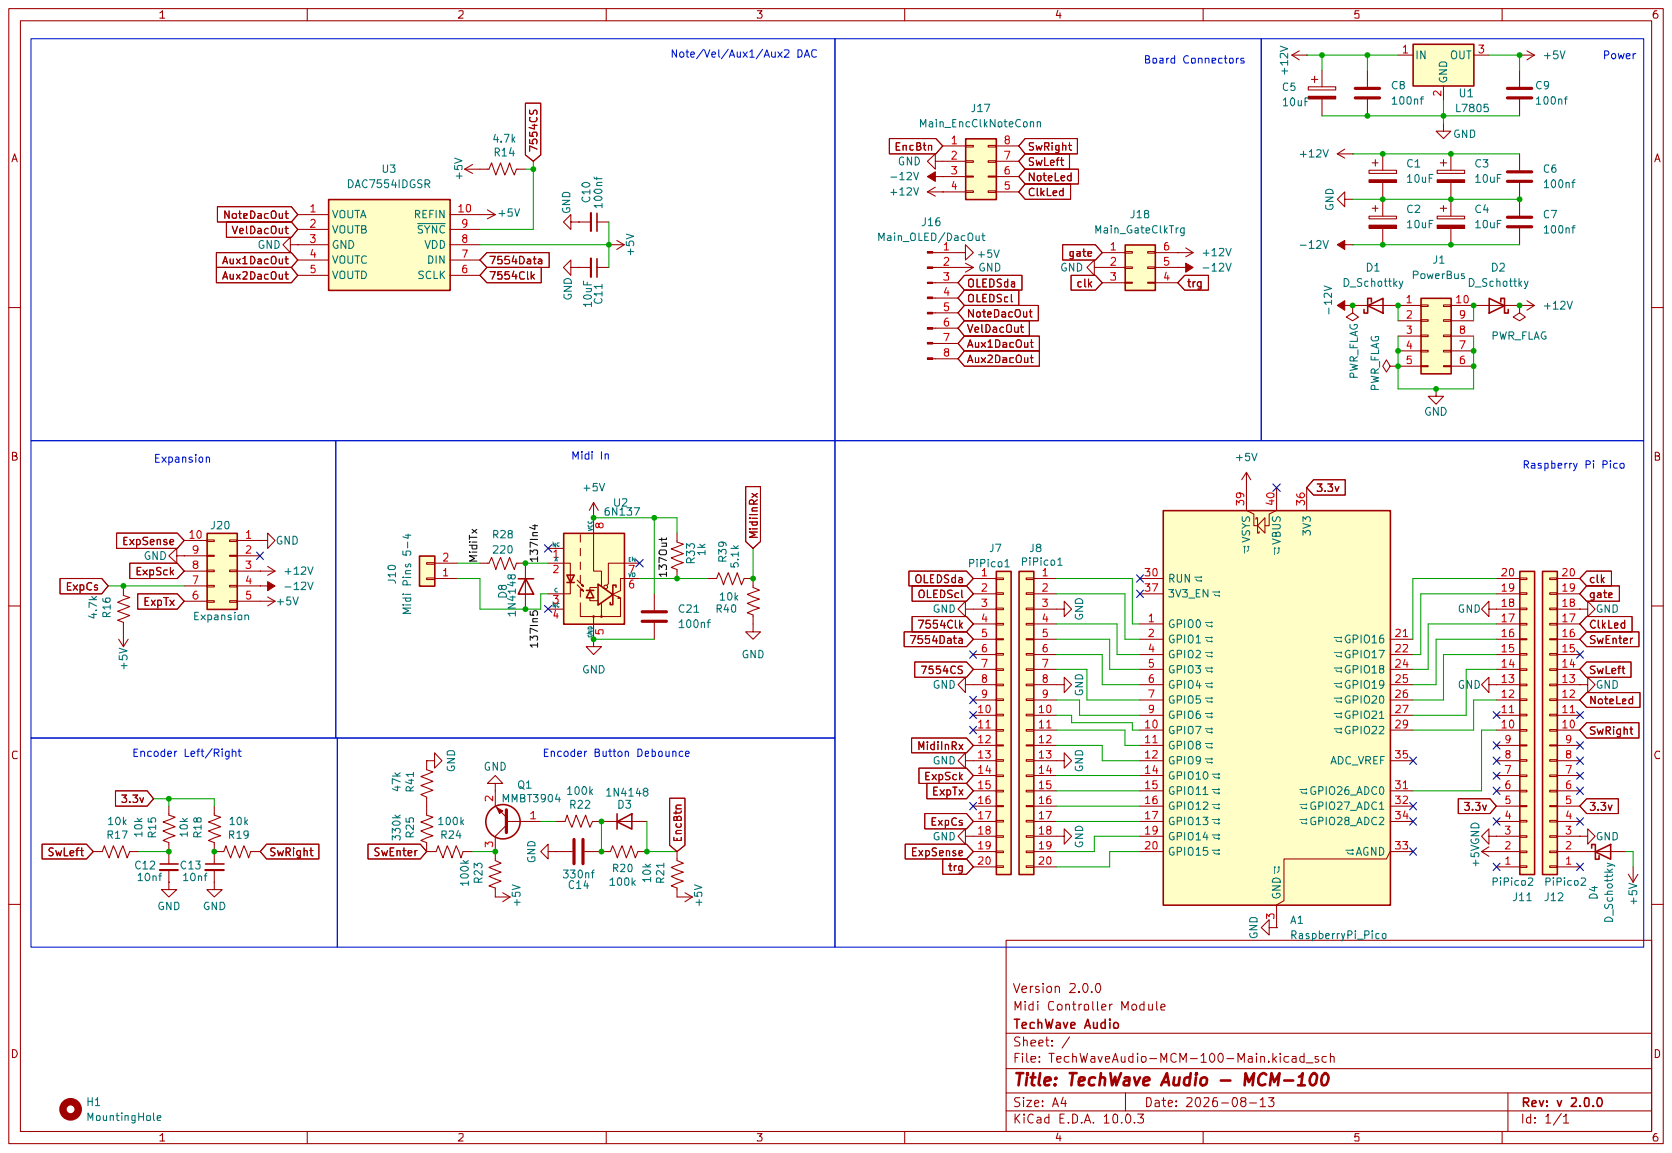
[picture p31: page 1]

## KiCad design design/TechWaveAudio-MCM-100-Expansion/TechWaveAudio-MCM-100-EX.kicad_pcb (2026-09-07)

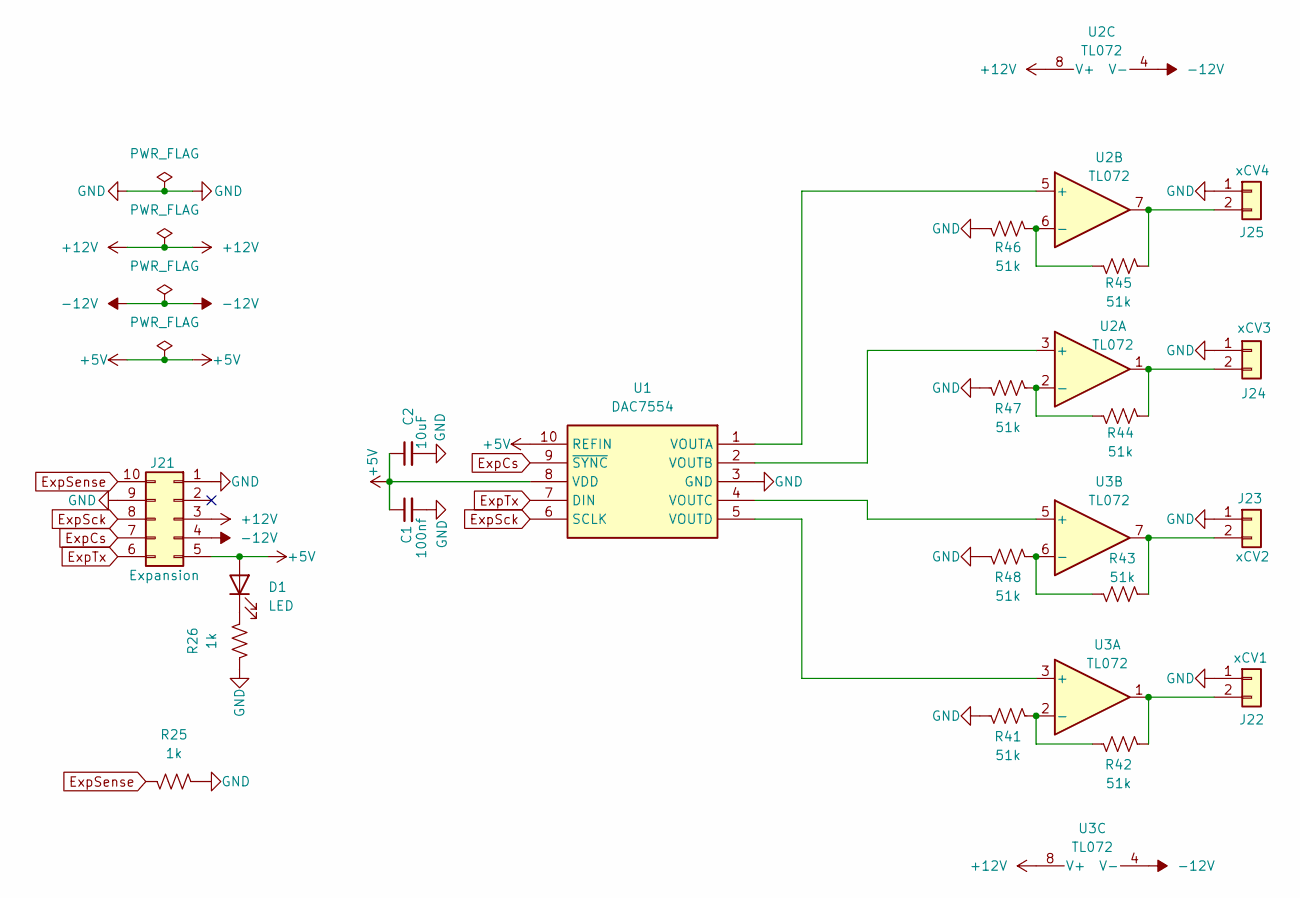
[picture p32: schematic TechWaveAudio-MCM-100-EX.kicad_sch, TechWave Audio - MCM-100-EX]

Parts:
C1: 100nf; C_0402_1005Metric; Voltage 1kV; Tolerance 100%
C2: 10uF; C_0805_2012Metric; Voltage 1kV; Tolerance 100%
D1: LED; LED_D3.0mm
J21: Expansion; IDC-Header_2x05_P2.54mm_Vertical
J22: xCV1; Audio_Jack_3.5mm_SameSky_SJ3-3505x
J23: xCV2; Audio_Jack_3.5mm_SameSky_SJ3-3505x
J24: xCV3; Audio_Jack_3.5mm_SameSky_SJ3-3505x
J25: xCV4; Audio_Jack_3.5mm_SameSky_SJ3-3505x
R25, R26: 1k; R_0402_1005Metric
R41, R42, R43, R44, R45, R46, R47, R48: 51k; R_0402_1005Metric
U1: DAC7554; MSOP-10_3x3mm_P0.5mm; Mouser Part Number 595-DAC7554IDGSR
U2, U3: TL072; SOIC-8_3.9x4.9mm_P1.27mm

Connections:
+5V: C1.1, C2.1, D1.2 (A), J21.5, U1.8 (VDD), U1.10 (REFIN)
+12V: J21.3, U2.8 (V+), U3.8 (V+)
-12V: J21.4, U2.4 (V-), U3.4 (V-)
ExpCs: J21.7, U1.9 (~SYNC)
ExpSck: J21.8, U1.6 (SCLK)
ExpSense: J21.10, R25.2
ExpTx: J21.6, U1.7 (DIN)
GND: C1.2, C2.2, J21.1, J21.9, J22.1, J23.1, J24.1, J25.1, R25.1, R26.2, R41.2, R46.2, R47.2, R48.2, U1.3 (GND)
unnamed: D1.1 (K), R26.1
unnamed: J22.2, R42.1, U3.1
unnamed: J23.2, R43.1, U3.7
unnamed: J24.2, R44.1, U2.1
unnamed: J25.2, R45.1, U2.7
unnamed: U1.1 (VOUTA), U2.5 (+)
unnamed: U1.2 (VOUTB), U2.3 (+)
unnamed: U1.4 (VOUTC), U3.5 (+)
unnamed: U1.5 (VOUTD), U3.3 (+)
unnamed: R44.2, R47.1, U2.2 (-)
unnamed: R45.2, R46.1, U2.6 (-)
unnamed: R41.1, R42.2, U3.2 (-)
unnamed: R43.2, R48.1, U3.6 (-)

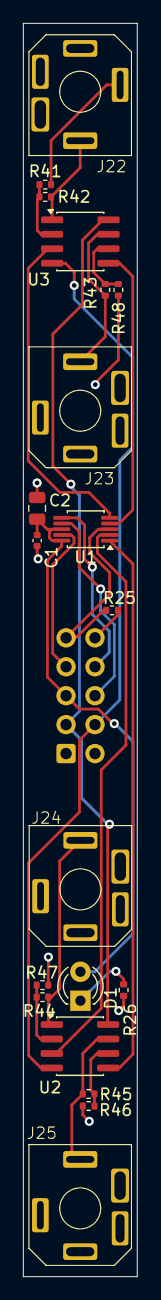
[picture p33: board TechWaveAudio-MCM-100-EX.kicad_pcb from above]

Board: 2 copper layers, 10.0 x 110.0 mm, 21 parts (1 on the bottom side), 21 nets.

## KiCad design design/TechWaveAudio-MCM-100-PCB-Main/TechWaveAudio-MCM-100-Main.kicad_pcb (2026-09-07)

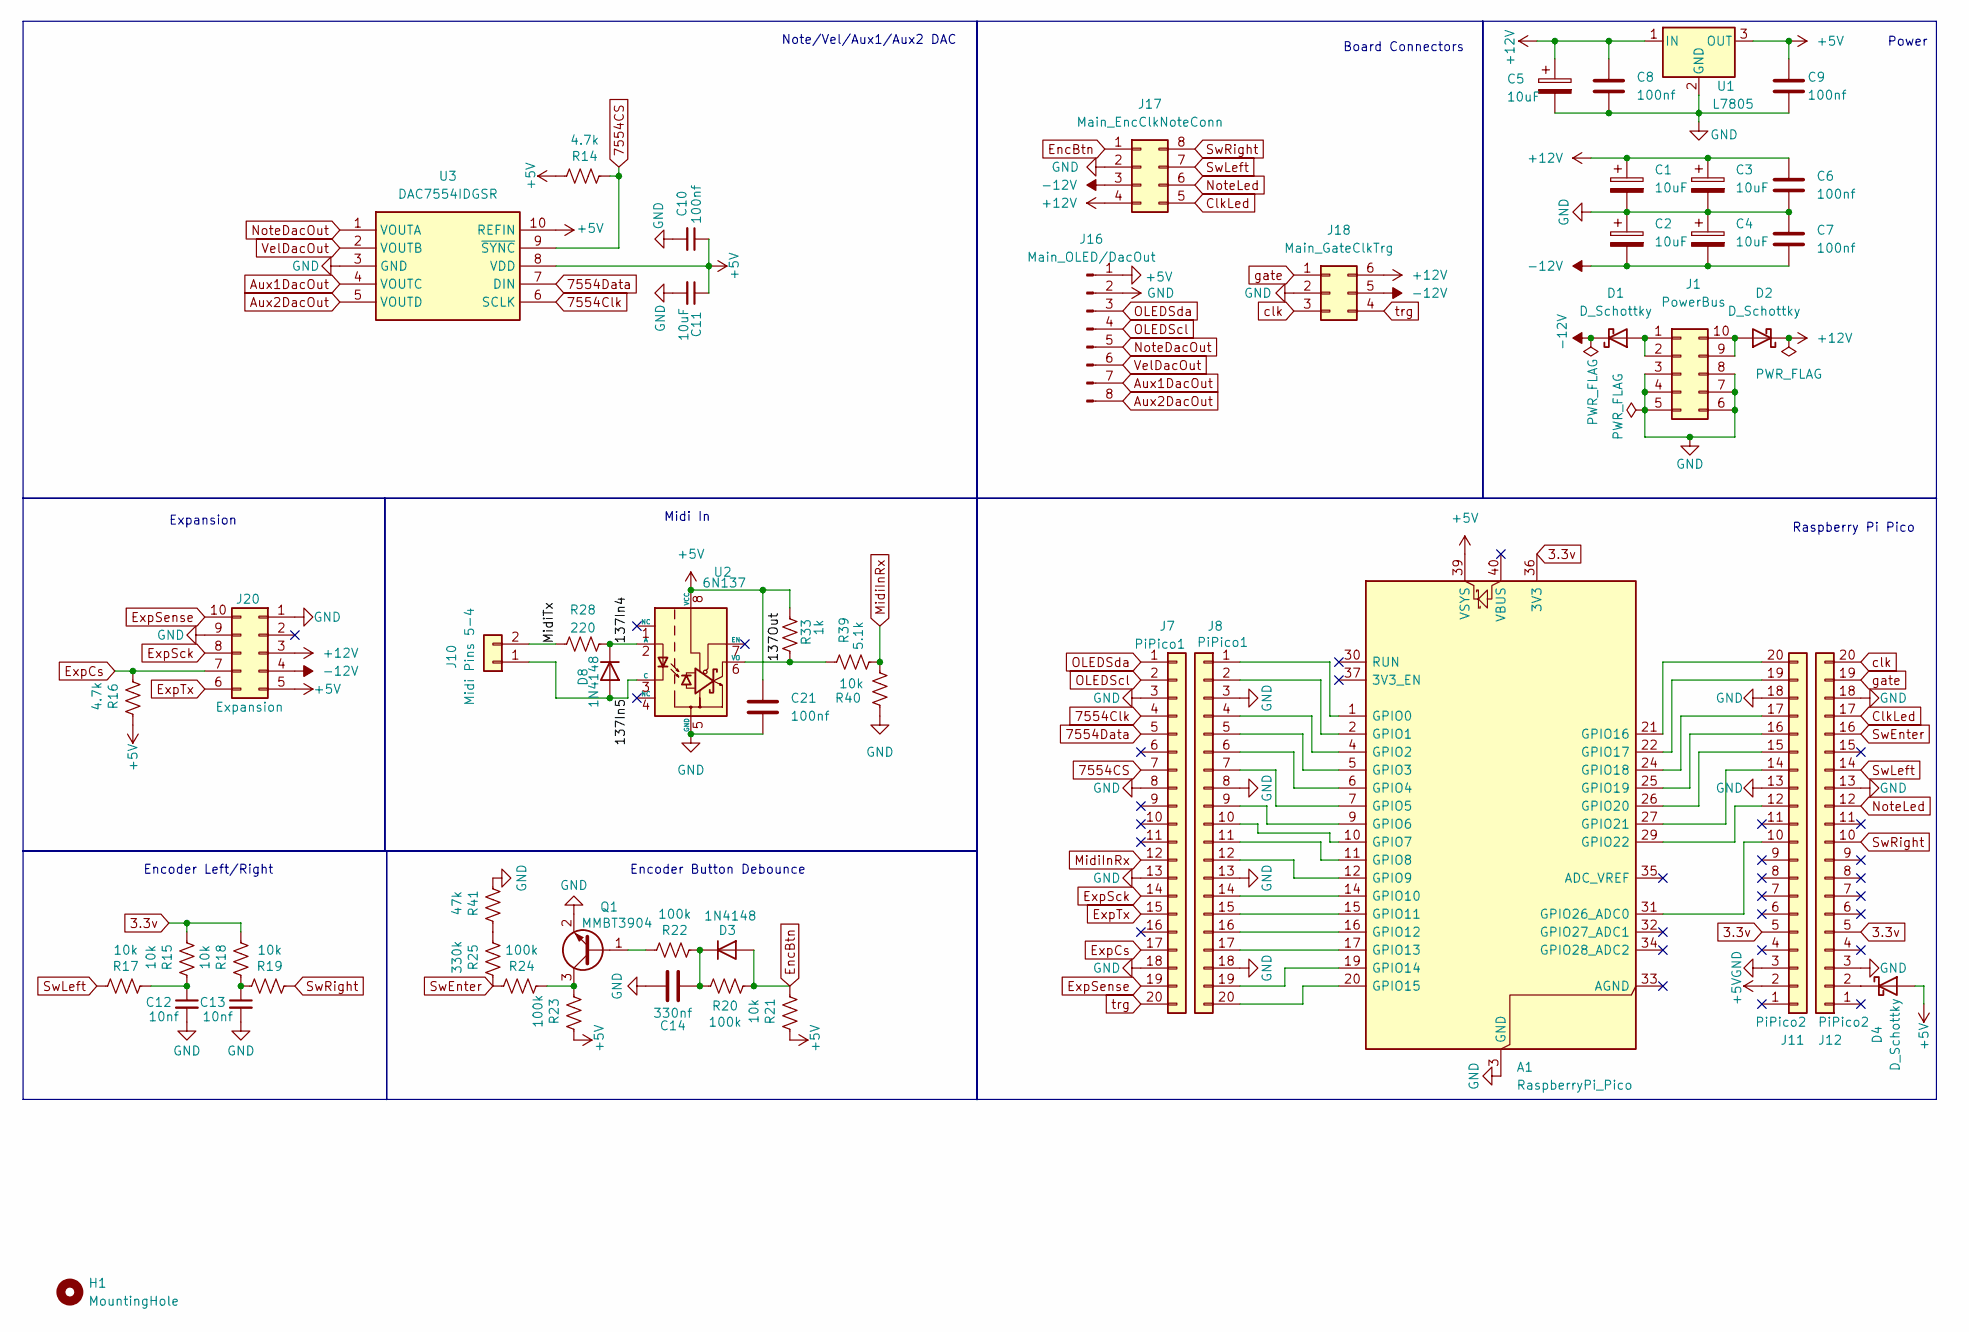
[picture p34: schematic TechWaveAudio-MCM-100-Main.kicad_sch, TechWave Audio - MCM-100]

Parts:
A1: RaspberryPi_Pico; DIP-40_W15.24mm_Socket
C1, C2, C3, C4, C5: 10uF; CP_EIA-6032-28_Kemet-C
C6, C7, C8, C9, C21: 100nf; C_0402_1005Metric
C10: 100nf; C_0402_1005Metric; Voltage 1kV; Tolerance 100%
C11: 10uF; C_0805_2012Metric; Voltage 1kV; Tolerance 100%
C12, C13: 10nf; C_0402_1005Metric; Voltage 1kV; Tolerance 100%
C14: 330nf; C_0402_1005Metric
D1, D2, D4: D_Schottky; D_0805_2012Metric
D3, D8: 1N4148; D_SOD-323
H1: MountingHole; MountingHole_3.2mm_M3
J1: PowerBus; IDC-Header_2x05_P2.54mm_Vertical
J7: PiPico1; PinHeader_1x20_P2.54mm_Vertical
J8: PiPico1
J10: Midi Pins 5-4; PinHeader_1x02_P2.54mm_Vertical
J11: PiPico2
J12: PiPico2; PinHeader_1x20_P2.54mm_Vertical
J16: Main_OLED/DacOut; PinHeader_1x08_P2.54mm_Vertical
J17: Main_EncClkNoteConn; PinHeader_2x04_P2.54mm_Vertical
J18: Main_GateClkTrg; PinHeader_2x03_P2.54mm_Vertical
J20: Expansion; PinHeader_2x05_P2.54mm_Vertical
Q1: MMBT3904; SOT-23
R14, R16: 4.7k; R_0402_1005Metric
R15, R17, R18, R19, R21, R40: 10k; R_0402_1005Metric
R20, R22, R23, R24: 100k; R_0402_1005Metric
R25: 330k; R_0402_1005Metric
R28: 220; R_0402_1005Metric
R33: 1k; R_0402_1005Metric
R39: 5.1k; R_0402_1005Metric
R41: 47k; R_0402_1005Metric
U1: L7805; SOT-223-3_TabPin2
U2: 6N137; DIP-8_W7.62mm
U3: DAC7554IDGSR; TSSOP-10_3x3mm_P0.5mm; Mouser Part Number 595-DAC7554IDGSR

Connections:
3.3v: A1.36 (3V3), J11.5, J12.5, R15.2, R18.2
7554CS: J7.7, R14.2, U3.9 (~SYNC)
7554Clk: J7.4, U3.6 (SCLK)
7554Data: J7.5, U3.7 (DIN)
+5V: A1.39 (VSYS), C9.1, C10.1, C11.1, C21.1, D4.2 (A), J11.2, J16.2, J20.5, R14.1, R16.1, R21.1, R23.1, R33.2, U1.3 (OUT), U2.8 (VCC), U3.8 (VDD), U3.10 (REFIN)
+12V: C1.1, C3.1, C5.1, C6.1, C8.1, D2.1 (K), J17.4, J18.6, J20.3, U1.1 (IN)
/137In4: D8.1 (K), R28.2, U2.2 (A)
/137In5: D8.2 (A), J10.1, U2.3 (C)
/137Out: R33.1, R39.1, U2.6 (VO)
/MidiTx: J10.2, R28.1
Aux1DacOut: J16.7, U3.4 (VOUTC)
Aux2DacOut: J16.8, U3.5 (VOUTD)
ClkLed: J12.17, J17.5
EncBtn: D3.2 (A), J17.1, R20.1, R21.2
ExpCs: J7.17, J20.7, R16.2
ExpSck: J7.14, J20.8
ExpSense: J7.19, J20.10
ExpTx: J7.15, J20.6
GND: A1.3 (GND), A1.8 (GND), A1.13 (GND), A1.18 (GND), A1.23 (GND), A1.28 (GND), A1.38 (GND), C1.2, C2.1, C3.2, C4.1, C5.2, C6.2, C7.1, C8.2, C9.2, C10.2, C11.2, C12.2, C13.2, C14.1, C21.2, J1.3, J1.4, J1.5, J1.6, J1.7, J1.8, J7.3, J7.8, J7.13, J7.18, J8.3, J8.8, J8.13, J8.18, J11.3, J11.13, J11.18, J12.3, J12.13, J12.18, J16.1, J17.2, J18.2, J20.1, J20.9, Q1.2 (E), R40.1, R41.2, U1.2 (GND), U2.5 (GND), U3.3 (GND)
MidiInRx: J7.12, R39.2, R40.2
unnamed: A1.1 (GPIO0), J8.1
unnamed: A1.2 (GPIO1), J8.2
unnamed: A1.4 (GPIO2), J8.4
unnamed: A1.5 (GPIO3), J8.5
unnamed: A1.6 (GPIO4), J8.6
unnamed: A1.7 (GPIO5), J8.7
unnamed: A1.9 (GPIO6), J8.9
unnamed: A1.10 (GPIO7), J8.10
unnamed: A1.11 (GPIO8), J8.11
unnamed: A1.12 (GPIO9), J8.12
unnamed: A1.14 (GPIO10), J8.14
unnamed: A1.15 (GPIO11), J8.15
unnamed: A1.16 (GPIO12), J8.16
unnamed: A1.17 (GPIO13), J8.17
unnamed: A1.19 (GPIO14), J8.19
unnamed: A1.20 (GPIO15), J8.20
unnamed: A1.21 (GPIO16), J11.20
unnamed: A1.22 (GPIO17), J11.19
unnamed: A1.24 (GPIO18), J11.17
unnamed: A1.25 (GPIO19), J11.16
unnamed: A1.26 (GPIO20), J11.15
unnamed: A1.27 (GPIO21), J11.14
unnamed: A1.29 (GPIO22), J11.12
unnamed: A1.31 (GPIO26_ADC0), J11.10
unnamed: C12.1, R15.1, R17.2
unnamed: C13.1, R18.1, R19.1
unnamed: D2.2 (A), J1.9, J1.10
unnamed: C14.2, D3.1 (K), R20.2, R22.2
unnamed: D4.1 (K), J12.2
unnamed: Q1.1 (B), R22.1
unnamed: Q1.3 (C), R23.2, R24.2
unnamed: R25.2, R41.1
NoteDacOut: J16.5, U3.1 (VOUTA)
NoteLed: J12.12, J17.6
OLEDScl: J7.2, J16.4
OLEDSda: J7.1, J16.3
SwEnter: J12.16, R24.1, R25.1
SwLeft: J12.14, J17.7, R17.1
SwRight: J12.10, J17.8, R19.2
VelDacOut: J16.6, U3.2 (VOUTB)
clk: J12.20, J18.3
gate: J12.19, J18.1
trg: J7.20, J18.4

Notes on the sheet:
Encoder Button Debounce
Note/Vel/Aux1/Aux2 DAC
Midi In
Power
Expansion
Raspberry Pi Pico
Encoder Left/Right
Board Connectors

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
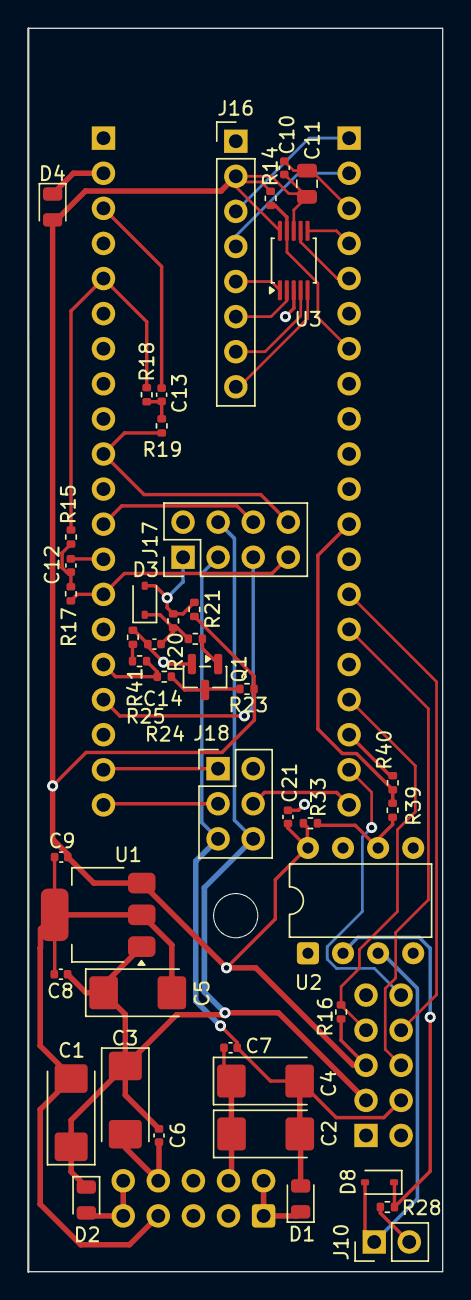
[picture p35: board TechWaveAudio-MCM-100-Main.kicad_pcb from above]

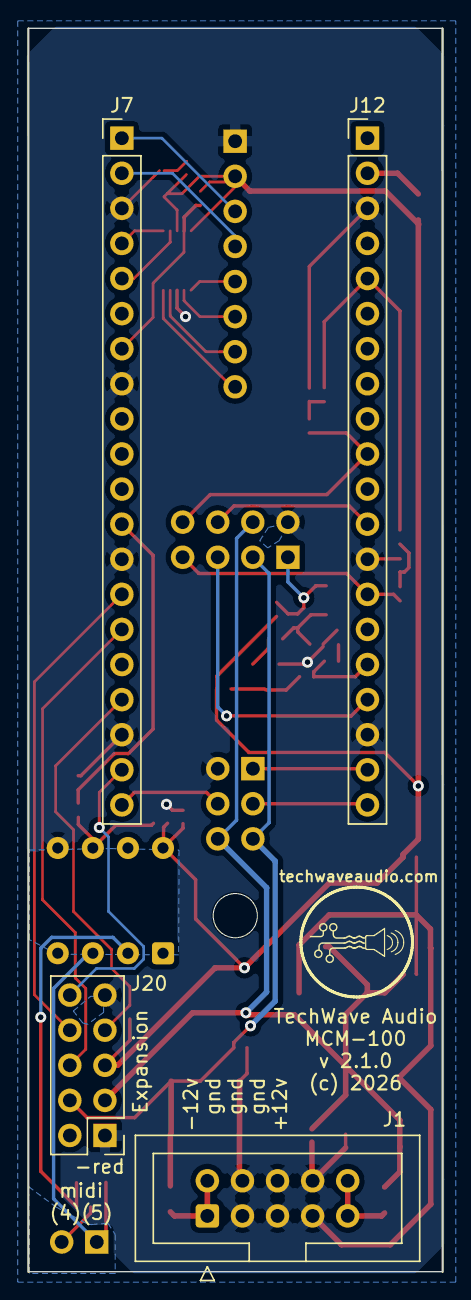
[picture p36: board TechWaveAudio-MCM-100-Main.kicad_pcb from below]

Board: 2 copper layers, 30.0 x 90.0 mm, 50 parts (4 on the bottom side), 41 nets.

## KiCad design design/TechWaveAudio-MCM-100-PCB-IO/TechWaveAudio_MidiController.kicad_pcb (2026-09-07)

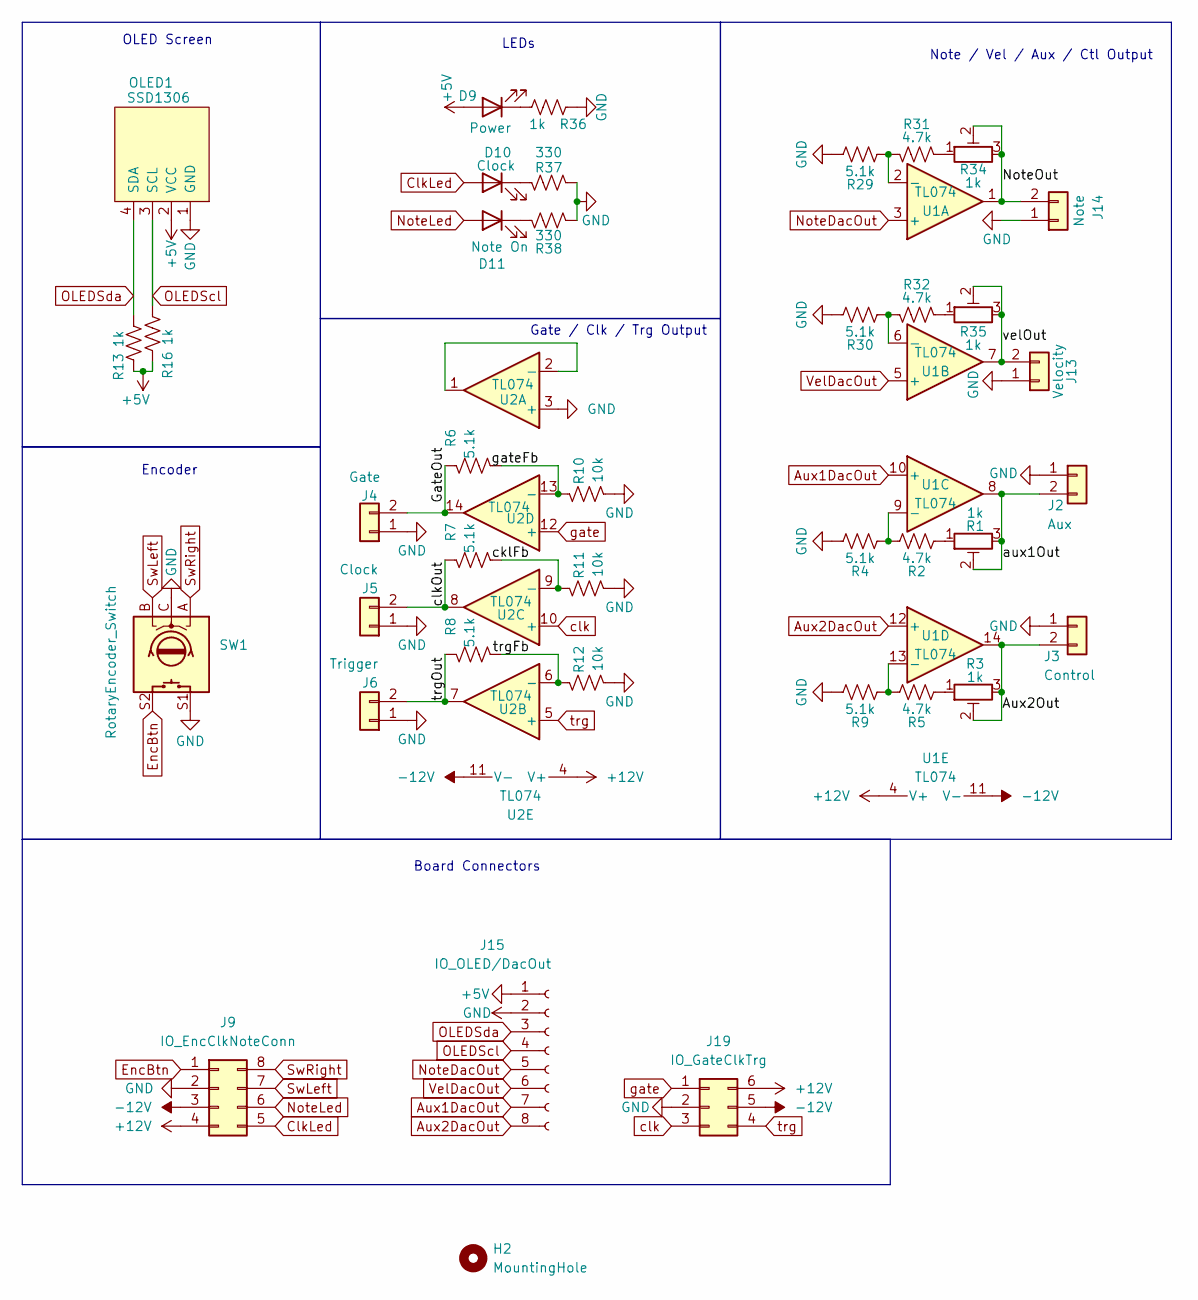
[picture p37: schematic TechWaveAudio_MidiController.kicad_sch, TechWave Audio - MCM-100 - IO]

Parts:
D9: Power; LED_D3.0mm
D10: Clock; LED_D3.0mm
D11: Note On; LED_D3.0mm
H2: MountingHole; MountingHole_3.2mm_M3
J2: Aux; Audio_Jack_3.5mm_SameSky_SJ3-3505x
J3: Control; Audio_Jack_3.5mm_SameSky_SJ3-3505x
J4: Gate; Audio_Jack_3.5mm_SameSky_SJ3-3505x
J5: Clock; Audio_Jack_3.5mm_SameSky_SJ3-3505x
J6: Trigger; Audio_Jack_3.5mm_SameSky_SJ3-3505x
J9: IO_EncClkNoteConn; PinSocket_2x04_P2.54mm_Vertical
J13: Velocity; Audio_Jack_3.5mm_SameSky_SJ3-3505x
J14: Note; Audio_Jack_3.5mm_SameSky_SJ3-3505x
J15: IO_OLED/DacOut; PinSocket_1x08_P2.54mm_Vertical
J19: IO_GateClkTrg; PinSocket_2x03_P2.54mm_Vertical
OLED1: SSD1306; PinSocket_1x04_P2.54mm_Vertical
R1, R3, R34, R35: 1k; Potentiometer_Bourns_3296X_Horizontal
R2, R5, R31, R32: 4.7k; R_0402_1005Metric
R4, R6, R7, R8, R9, R29, R30: 5.1k; R_0402_1005Metric
R10, R11, R12: 10k; R_0402_1005Metric
R13, R16, R36: 1k; R_0402_1005Metric
R37, R38: 330; R_0402_1005Metric
SW1: RotaryEncoder_Switch; Rotary_Encoder-PEC11-Breakout_Board
U1, U2: TL074; SOIC-14_3.9x8.7mm_P1.27mm

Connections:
+5V: D9.2 (A), J15.2, OLED1.2 (VCC), R13.1, R16.1
+12V: J9.4, J19.6, U1.4 (V+), U2.4 (V+)
-12V: J9.3, J19.5, U1.11 (V-), U2.11 (V-)
/Aux2Out: J3.2, R3.2, R3.3, U1.14
/GateOut: J4.2, R6.1, U2.14
/NoteOut: J14.2, R34.2, R34.3, U1.1
/aux1Out: J2.2, R1.2, R1.3, U1.8
/cklFb: R7.2, R11.1, U2.9 (-)
/clkOut: J5.2, R7.1, U2.8
/gateFb: R6.2, R10.1, U2.13 (-)
/trgFb: R8.2, R12.1, U2.6 (-)
/trgOut: J6.2, R8.1, U2.7
/velOut: J13.2, R35.2, R35.3, U1.7
Aux1DacOut: J15.7, U1.10 (+)
Aux2DacOut: J15.8, U1.12 (+)
ClkLed: D10.2 (A), J9.5
EncBtn: J9.1, SW1.S2
GND: J2.1, J3.1, J4.1, J5.1, J6.1, J9.2, J13.1, J14.1, J15.1, J19.2, OLED1.1 (GND), R4.1, R9.1, R10.2, R11.2, R12.2, R29.1, R30.1, R36.2, R37.2, R38.2, SW1.C, SW1.S1, U2.3 (+)
unnamed: D9.1 (K), R36.1
unnamed: D10.1 (K), R37.1
unnamed: D11.1 (K), R38.1
unnamed: R1.1, R2.2
unnamed: R3.1, R5.2
unnamed: R31.2, R34.1
unnamed: R32.2, R35.1
unnamed: R29.2, R31.1, U1.2 (-)
unnamed: R30.2, R32.1, U1.6 (-)
unnamed: R2.1, R4.2, U1.9 (-)
unnamed: R5.1, R9.2, U1.13 (-)
unnamed: U2.1, U2.2 (-)
NoteDacOut: J15.5, U1.3 (+)
NoteLed: D11.2 (A), J9.6
OLEDScl: J15.4, OLED1.3 (SCL), R16.2
OLEDSda: J15.3, OLED1.4 (SDA), R13.2
SwLeft: J9.7, SW1.B
SwRight: J9.8, SW1.A
VelDacOut: J15.6, U1.5 (+)
clk: J19.3, U2.10 (+)
gate: J19.1, U2.12 (+)
trg: J19.4, U2.5 (+)

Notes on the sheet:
Board Connectors
Note / Vel / Aux / Ctl Output
Encoder
Gate / Clk / Trg Output
OLED Screen
LEDs

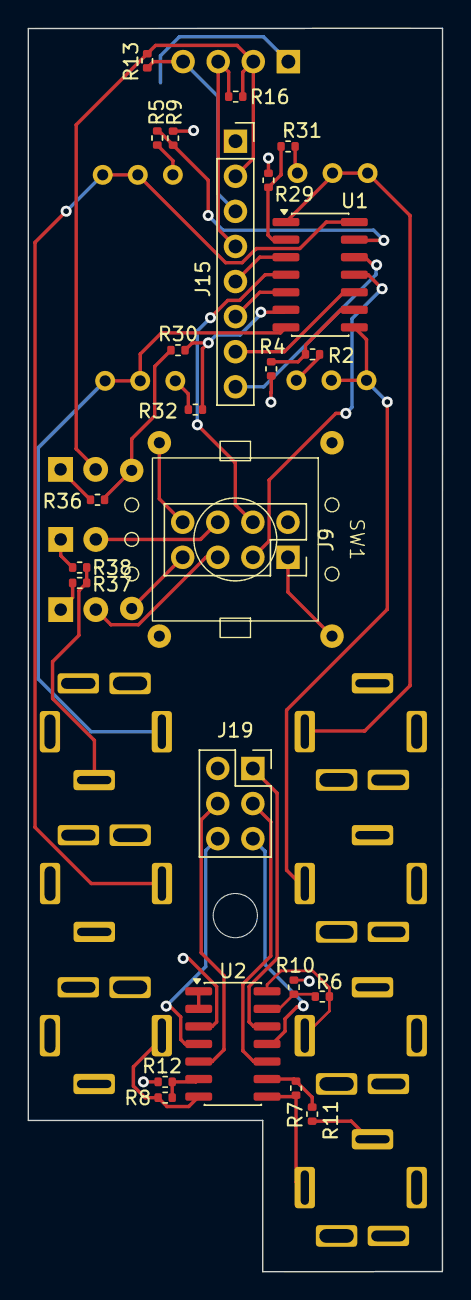
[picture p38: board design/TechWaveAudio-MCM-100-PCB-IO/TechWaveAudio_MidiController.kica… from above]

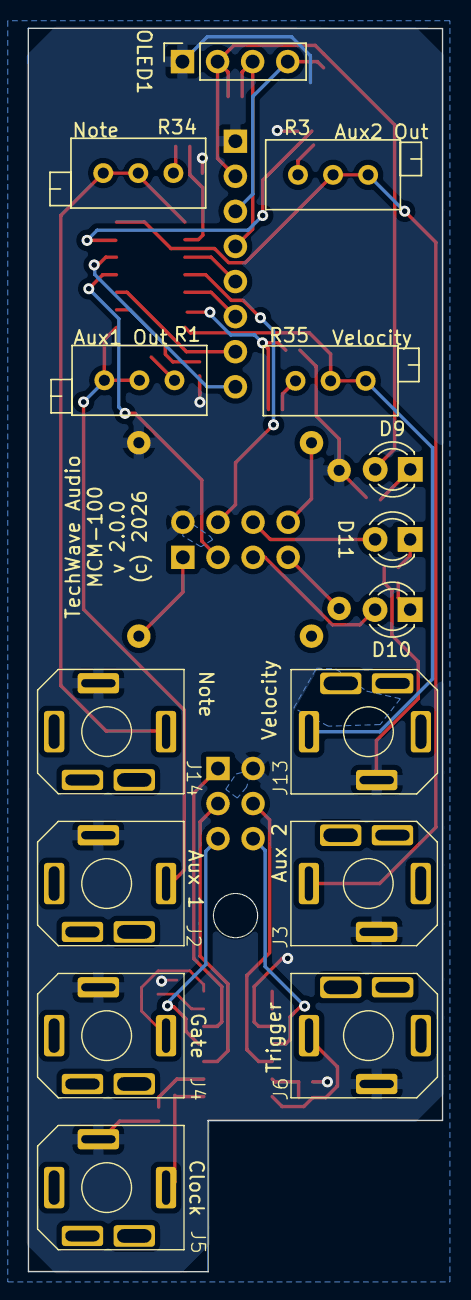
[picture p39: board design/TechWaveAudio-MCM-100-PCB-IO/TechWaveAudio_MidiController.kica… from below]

Board: 2 copper layers, 30.0 x 90.0 mm, 41 parts (15 on the bottom side), 40 nets.

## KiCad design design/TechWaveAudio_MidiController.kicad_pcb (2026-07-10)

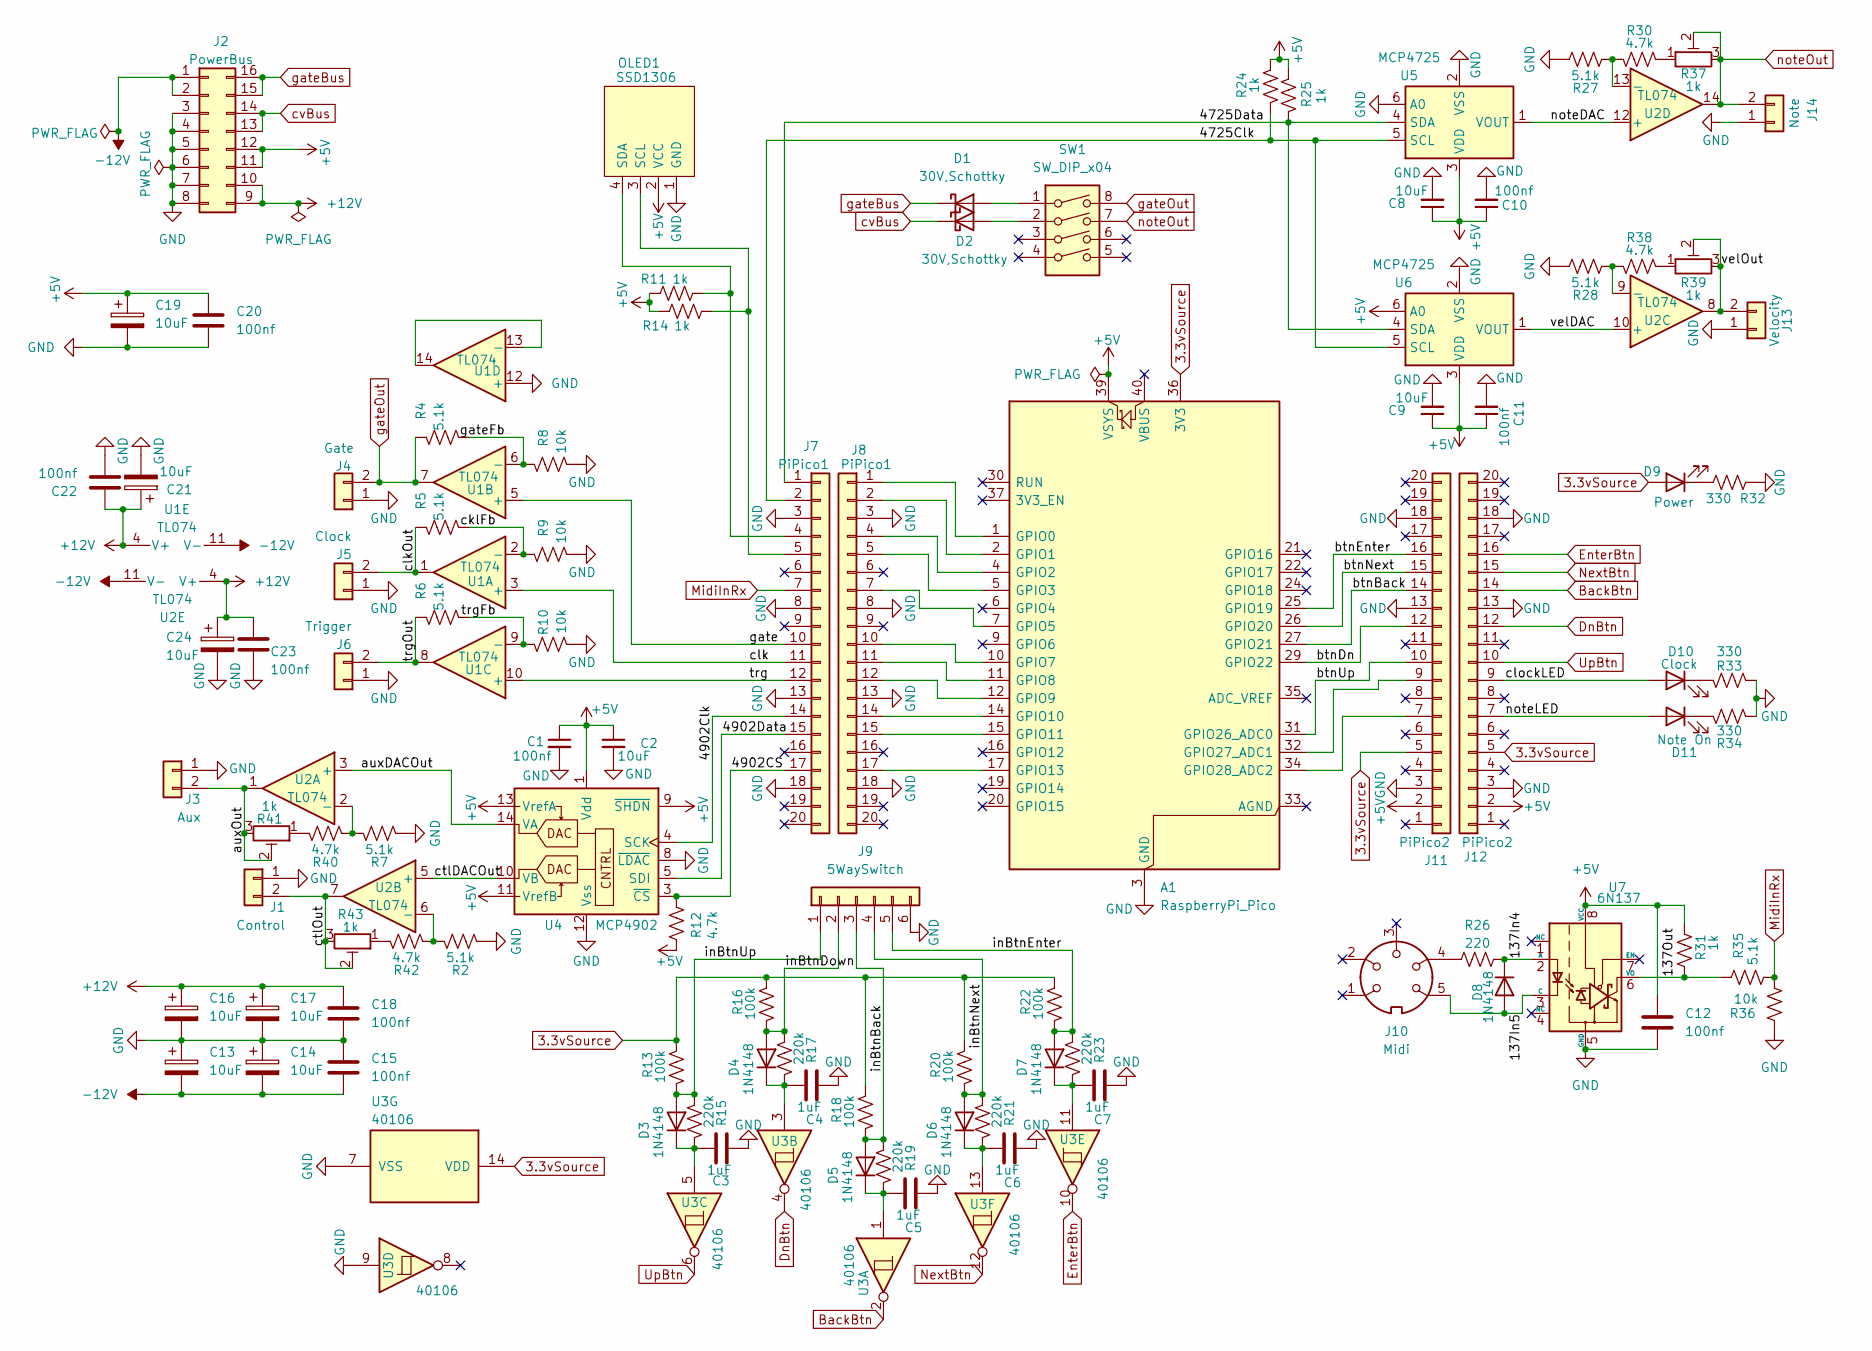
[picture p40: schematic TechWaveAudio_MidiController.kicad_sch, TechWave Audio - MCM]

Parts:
A1: RaspberryPi_Pico; DIP-40_W15.24mm_Socket
C1, C10, C11: 100nf; C_0402_1005Metric; Voltage 1kV; Tolerance 100%
C2, C8, C9: 10uF; C_0805_2012Metric; Voltage 1kV; Tolerance 100%
C3, C4, C5, C6, C7: 1uF; C_0402_1005Metric
C12, C15, C18, C20, C22, C23: 100nf; C_0402_1005Metric
C13, C14, C16, C17, C19, C21, C24: 10uF; C_0805_2012Metric
D1, D2: 30V,Schottky; SOT-23
D3, D4, D5, D6, D7, D8: 1N4148; D_SOD-323
D9: Power; LED_Rectangular_W5.0mm_H2.0mm
D10: Clock; LED_Rectangular_W5.0mm_H2.0mm
D11: Note On; LED_Rectangular_W5.0mm_H2.0mm
J1: Control; Jack_3.5mm_SameSky_SJ3-3505x
J2: PowerBus; IDC-Header_2x08_P2.54mm_Vertical
J3: Aux; Jack_3.5mm_SameSky_SJ3-3505x
J4: Gate; Jack_3.5mm_SameSky_SJ3-3505x
J5: Clock; Jack_3.5mm_SameSky_SJ3-3505x
J6: Trigger; Jack_3.5mm_SameSky_SJ3-3505x
J7: PiPico1; PinSocket_1x20_P2.54mm_Vertical
J8: PiPico1
J9: 5WaySwitch; PinSocket_1x06_P2.54mm_Vertical
J10: Midi; PinHeader_1x05_P2.54mm_Vertical
J11: PiPico2
J12: PiPico2; PinSocket_1x20_P2.54mm_Vertical
J13: Velocity; Jack_3.5mm_SameSky_SJ3-3505x
J14: Note; Jack_3.5mm_SameSky_SJ3-3505x
OLED1: SSD1306; PinSocket_1x04_P2.54mm_Vertical
R2, R4, R5, R6, R7, R27, R28, R35: 5.1k; R_0402_1005Metric
R8, R9, R10, R36: 10k; R_0402_1005Metric
R11, R14, R24, R25, R31: 1k; R_0402_1005Metric
R12, R30, R38, R40, R42: 4.7k; R_0402_1005Metric
R13, R16, R18, R20, R22: 100k; R_0402_1005Metric
R15, R17, R19, R21, R23: 220k; R_0402_1005Metric
R26: 220; R_0402_1005Metric
R32, R33, R34: 330; R_0402_1005Metric
R37, R39, R41, R43: 1k; Potentiometer_Bourns_3296X_Horizontal
SW1: SW_DIP_x04; DIP-8_W7.62mm
U1, U2: TL074; SOIC-14_3.9x8.7mm_P1.27mm
U3: 40106; TSSOP-14_4.4x5mm_P0.65mm
U4: MCP4902; TSSOP-14_4.4x5mm_P0.65mm
U5, U6: MCP4725; SOT-23-6
U7: 6N137; DIP-8_W7.62mm

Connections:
3.3vSource: A1.36 (3V3), D9.2 (A), J11.5, J12.5, R13.2, R16.2, R18.2, R20.2, R22.2, U3.14 (VDD)
+5V: A1.39 (VSYS), C1.1, C2.1, C8.1, C9.1, C10.1, C11.1, C12.1, C19.1, C20.1, J2.11, J2.12, J11.2, J12.2, OLED1.2 (VCC), R11.1, R12.2, R14.1, R24.1, R25.1, R31.2, U4.1 (Vdd), U4.9 (~SHDN), U4.11 (VrefB), U4.13 (VrefA), U5.3 (VDD), U6.3 (VDD), U6.6 (A0), U7.8 (VCC)
+12V: C16.1, C17.1, C18.1, C21.1, C22.1, C23.1, C24.1, J2.9, J2.10, U1.4 (V+), U2.4 (V+)
-12V: C13.2, C14.2, C15.2, J2.1, J2.2, U1.11 (V-), U2.11 (V-)
/137In4: D8.1 (K), R26.2, U7.2 (A)
/137In5: D8.2 (A), J10.5, U7.3 (C)
/137Out: R31.1, R35.1, U7.6 (VO)
/4725Clk: J7.2, R24.2, U5.5 (SCL), U6.5 (SCL)
/4725Data: J7.1, R25.2, U5.4 (SDA), U6.4 (SDA)
/4902CS: J7.17, R12.1, U4.3 (~CS)
/4902Clk: J7.14, U4.4 (SCK)
/4902Data: J7.15, U4.5 (SDI)
/auxDACOut: U2.3 (+), U4.14 (VA)
/auxOut: J3.2, R41.2, R41.3, U2.1
/cklFb: R5.2, R9.1, U1.2 (-)
/clk: J7.11, U1.3 (+)
/clkOut: J5.2, R5.1, U1.1
/clockLED: D10.2 (A), J12.9
/ctlDACOut: U2.5 (+), U4.10 (VB)
/ctlOut: J1.2, R43.2, R43.3, U2.7
/gate: J7.10, U1.5 (+)
/gateFb: R4.2, R8.1, U1.6 (-)
/inBtnBack: D5.2 (A), J9.3, R18.1, R19.1
/inBtnDown: D4.2 (A), J9.2, R16.1, R17.1
/inBtnEnter: D7.2 (A), J9.5, R22.1, R23.1
/inBtnNext: D6.2 (A), J9.4, R20.1, R21.1
/inBtnUp: D3.2 (A), J9.1, R13.1, R15.1
/noteDAC: U2.12 (+), U5.1 (VOUT)
/noteLED: D11.2 (A), J12.7
/trg: J7.12, U1.10 (+)
/trgFb: R6.2, R10.1, U1.9 (-)
/trgOut: J6.2, R6.1, U1.8
/velDAC: U2.10 (+), U6.1 (VOUT)
/velOut: J13.2, R39.2, R39.3, U2.8
BackBtn: J12.14, U3.2
DnBtn: J12.12, U3.4
EnterBtn: J12.16, U3.10
GND: A1.3 (GND), A1.8 (GND), A1.13 (GND), A1.18 (GND), A1.23 (GND), A1.28 (GND), A1.38 (GND), C1.2, C2.2, C3.1, C4.1, C5.1, C6.1, C7.1, C8.2, C9.2, C10.2, C11.2, C12.2, C13.1, C14.1, C15.1, C16.2, C17.2, C18.2, C19.2, C20.2, C21.2, C22.2, C23.2, C24.2, J1.1, J2.3, J2.4, J2.5, J2.6, J2.7, J2.8, J3.1, J4.1, J5.1, J6.1, J7.3, J7.8, J7.13, J7.18, J8.3, J8.8, J8.13, J8.18, J9.6, J11.3, J11.13, J11.18, J12.3, J12.13, J12.18, J13.1, J14.1, OLED1.1 (GND), R2.1, R7.1, R8.2, R9.2, R10.2, R27.1, R28.1, R32.2, R33.2, R34.2, R36.1, U1.12 (+), U3.7 (VSS), U3.9, U4.8 (~LDAC), U4.12 (Vss), U5.2 (VSS), U5.6 (A0), U6.2 (VSS), U7.5 (GND)
MidiInRx: J7.7, R35.2, R36.2
unnamed: A1.1 (GPIO0), J8.1
unnamed: A1.2 (GPIO1), J8.2
unnamed: A1.4 (GPIO2), J8.4
unnamed: A1.5 (GPIO3), J8.5
unnamed: A1.7 (GPIO5), J8.7
unnamed: A1.10 (GPIO7), J8.10
unnamed: A1.11 (GPIO8), J8.11
unnamed: A1.12 (GPIO9), J8.12
unnamed: A1.14 (GPIO10), J8.14
unnamed: A1.15 (GPIO11), J8.15
unnamed: A1.17 (GPIO13), J8.17
unnamed: A1.25 (GPIO19), J11.16
unnamed: A1.26 (GPIO20), J11.15
unnamed: A1.27 (GPIO21), J11.14
unnamed: A1.29 (GPIO22), J11.12
unnamed: A1.31 (GPIO26_ADC0), J11.10
unnamed: A1.32 (GPIO27_ADC1), J11.9
unnamed: A1.34 (GPIO28_ADC2), J11.7
unnamed: D1.2 (A), SW1.1
unnamed: D2.2 (A), SW1.2
unnamed: C3.2, D3.1 (K), R15.2, U3.5
unnamed: C4.2, D4.1 (K), R17.2, U3.3
unnamed: C5.2, D5.1 (K), R19.2, U3.1
unnamed: C6.2, D6.1 (K), R21.2, U3.13
unnamed: C7.2, D7.1 (K), R23.2, U3.11
unnamed: D9.1 (K), R32.1
unnamed: D10.1 (K), R33.1
unnamed: D11.1 (K), R34.1
unnamed: J7.4, OLED1.4 (SDA), R11.2
unnamed: J7.5, OLED1.3 (SCL), R14.2
unnamed: J10.4, R26.1
unnamed: R30.2, R37.1
unnamed: R38.2, R39.1
unnamed: R40.2, R41.1
unnamed: R42.2, R43.1
unnamed: U1.13 (-), U1.14
unnamed: R7.2, R40.1, U2.2 (-)
unnamed: R2.2, R42.1, U2.6 (-)
unnamed: R28.2, R38.1, U2.9 (-)
unnamed: R27.2, R30.1, U2.13 (-)
NextBtn: J12.15, U3.12
UpBtn: J12.10, U3.6
cvBus: D2.1 (K), J2.13, J2.14
gateBus: D1.1 (K), J2.15, J2.16
gateOut: J4.2, R4.1, SW1.8, U1.7
noteOut: J14.2, R37.2, R37.3, SW1.7, U2.14

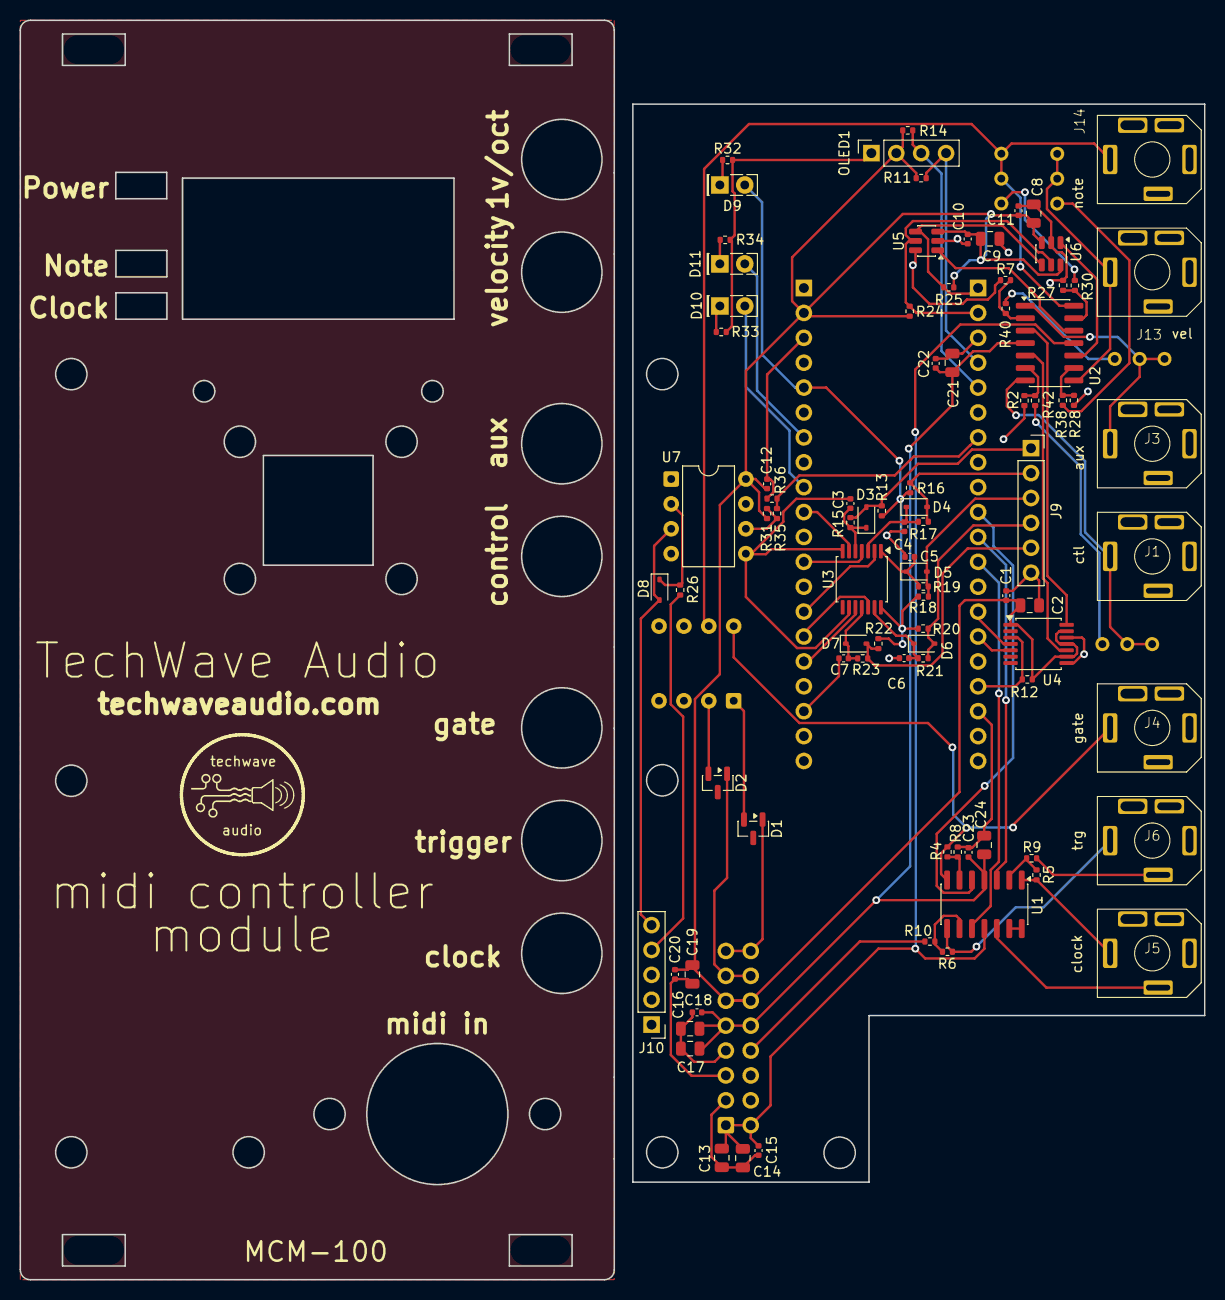
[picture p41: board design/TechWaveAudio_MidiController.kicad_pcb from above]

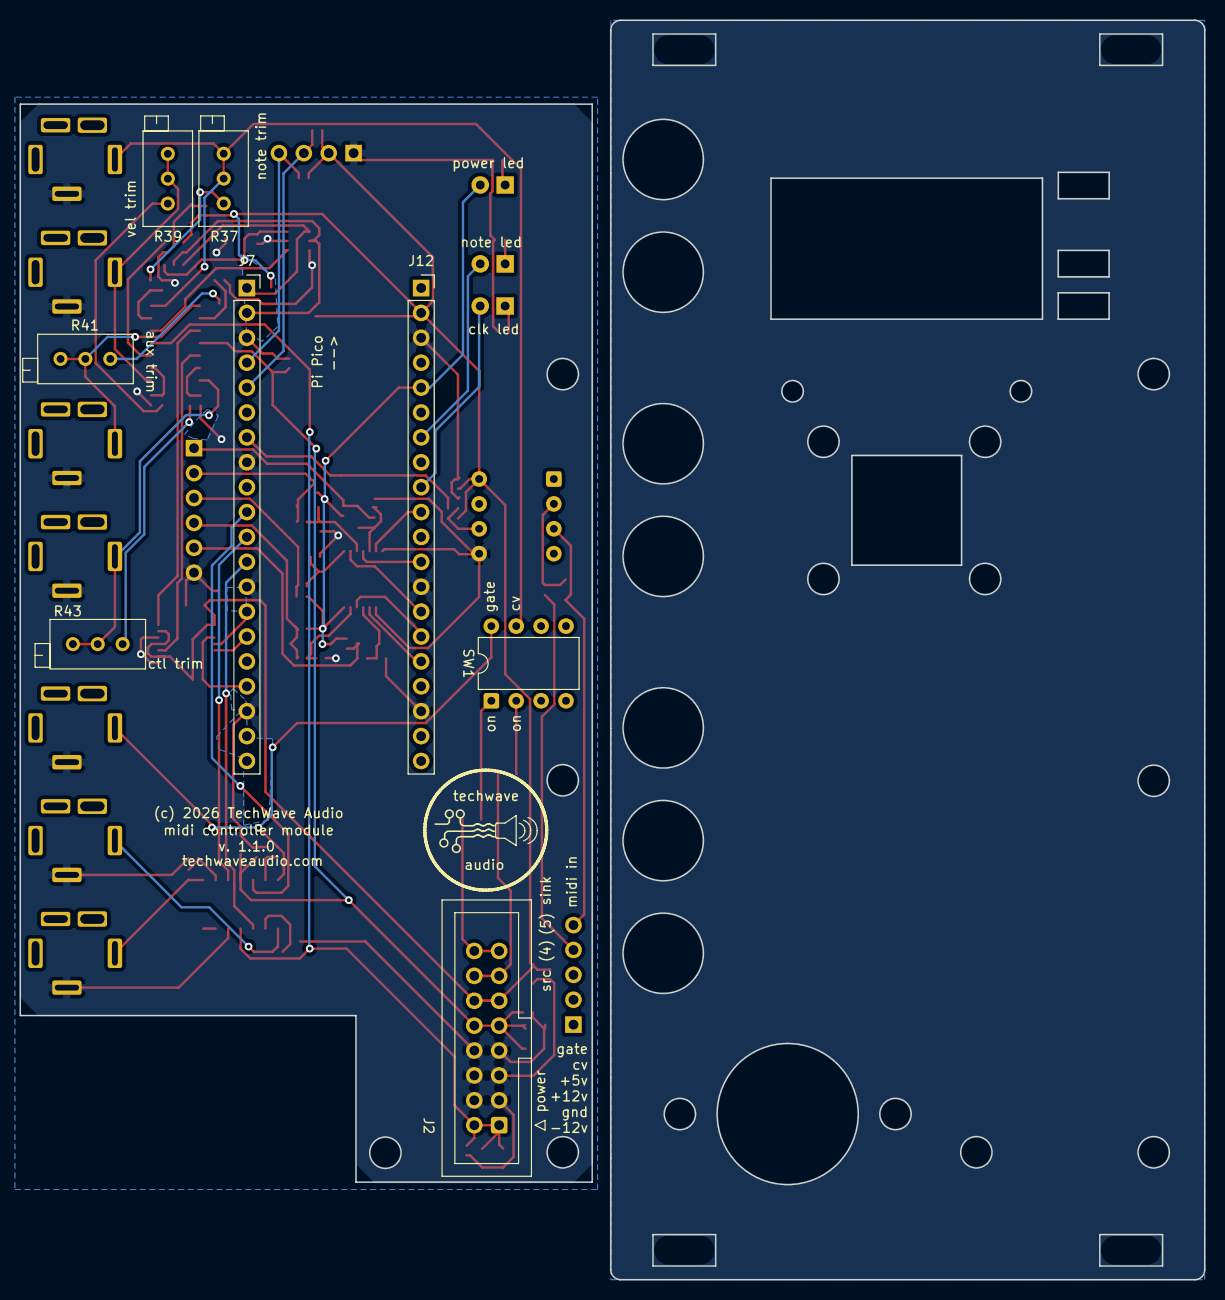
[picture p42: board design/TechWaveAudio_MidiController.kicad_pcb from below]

Board: 2 copper layers, 120.8 x 128.5 mm, 96 parts (8 on the bottom side), 67 nets.

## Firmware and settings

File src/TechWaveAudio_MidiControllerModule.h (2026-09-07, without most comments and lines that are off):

#define TECHWAVEAUDIO_MIDI_CONTROLLER_MODULE_H
#include <functional>
#include <stdexcept>
#include <string>
#include "hardware/flash.h"
#include "pico/time.h"
#define TECHWAVEAUDIO_MCM_VERSION 2.0.0
#define TECHWAVEAUDIO_MCM_VERSION_STR "    v2.0.0"
#define TECHWAVEAUDIO_MCM_RELEASE_STR " rel: 260901r1"
#define FLASH_TARGET_OFFSET (PICO_FLASH_SIZE_BYTES - FLASH_SECTOR_SIZE)
#define MAX_WEAR_LEVEL_PAGES (FLASH_SECTOR_SIZE / FLASH_PAGE_SIZE)
#define STATE_INVALID_PAGE 0xFFFFFFFF
#define STATE_START_MARKER 0x210F
#define MAX_CV_OCTAVE_RANGES 10.0f
#define MAX_CV_NOTE_VALUES (12.0f * MAX_CV_OCTAVE_RANGES)
#define ONBOARD_LED_PIN 25
#define ENC_LEFT_PIN 21
#define ENC_RIGHT_PIN 26
#define ENC_BUTTON_PIN 19
#define OLED_I2C_DATA_PIN 0
#define OLED_I2C_CLOCK_PIN 1
#define DAC_7554_SPI_CLOCK_PIN 2
#define DAC_7554_SPI_TX_PIN 3
#define DAC_7554_SPI_RX_PIN 4
#define DAC_7554_SPI_CS_PIN 5
#define MIDI_IN_RX_PIN 9
#define MIDI_OUT_TX_PIN 8
#define PIN_GATE_LINE 17
#define PIN_CLOCK_LINE 16
#define PIN_TRIGGER_LINE 15
#define PIN_CLOCK_LED 18
#define PIN_NOTE_LED 22
#define PIN_EX_SPI_CLOCK 10
#define PIN_EX_SPI_TX 11
#define PIN_EX_SPI_RX 12
#define PIN_EX_SPI_CS 13
#define PIN_EX_SENSE 14
#define HW_OLED_I2C i2c0_inst
#define OLED_BUS_NUMBER 0
#define OLED_ADDRESS 0x3C
#define OLED_BUS_HARDWARE_FREQ 2000000
#define OLED_DISPLAY_WIDTH 128
#define OLED_DISPLAY_HEIGHT 64
#define RANGE_DISPLAY_STEPS 13
#define DEFAULT_SHOW_DASHBOARD 1
#define DEFAULT_DASHBOARD_UPDATE_FREQUENCY 25
#define NUM_DASHBOARD_UPDATE_VALUES 7
static uint32_t display_update_values[NUM_DASHBOARD_UPDATE_VALUES] = {
    25, 50, 75, 100, 150, 200, 250
};
#define DEFAULT_CLOCK_TICK_LED_CYCLE 12
#define NUM_CLOCK_TICK_LED_VALUES 7
static uint8_t clock_led_toggle_values[NUM_CLOCK_TICK_LED_VALUES] = {
    0, 1, 2, 3, 6, 12, 24
};
#define DEFAULT_SCREEN_BRIGHTNESS 12
enum OledFontType {
    OledFontType_8x16 = 0x00,
    OledFontType_8x8 = 0x01,
};
#define OLED_NUM_FONTS 2
#define OLED_DEFAULT_FONT OledFontType_8x16
#define OLED_MENU_ITEM_FONT OledFontType_8x8
#define OLED_FONT_MAPPINGS { new CharacterMapping8x16(), new CharacterMapping8x8() }
#define OLED_PIXELS_PER_CHAR 8
#define OLED_MAX_NUM_TEXT_LINES 8
#define OLED_NUM_CHARS_PER_LINE 16
#define OLED_PIXELS_PER_LINE (OLED_DISPLAY_HEIGHT / OLED_NUM_TEXT_LINES)
#define OLED_LINE_TEXT_OFFSET 0
#define OLED_MENU_LINE_START 2
#define MENU_SYSTEM_NUM_LINES (OLED_MAX_NUM_TEXT_LINES - OLED_MENU_LINE_START)
#define MIDI_BAUD_RATE 31250
#define MAX_MIDI_DATA_VALUE 128
#define MIDI_UART_ID uart1
#define MIDI_UART_IRQ UART1_IRQ
#define DEFAULT_MIDI_CHANNEL 1
#define DEFAULT_PITCH_ADJUST 0.0f
#define MIN_PITCH_ADJUST (-250.0f)
#define MAX_PITCH_ADJUST 250.0f
#define DEFAULT_VELOCITY_ADJUST 0
#define MIN_VELOCITY_ADJUST (-250.0f)
#define MAX_VELOCITY_ADJUST 250.0f
#define DEFAULT_TRIGGER_DURATION 100
#define CLOCK_PULSE_MS 10
#define RESET_PULSE_DURATION_MS 10
#define DEFAULT_PITCH_BEND_RANGE_OCTAVES 1
#define MAX_PITCH_BEND_RANGE_OCTAVES 5.0f
#define PITCH_BEND_ZERO_TOLERANCE 256
#define MIDI_CMD_NOTE_OFF 0x80
#define MIDI_CMD_NOTE_ON 0x90
#define MIDI_CMD_POLY_AFTERTOUCH 0xA0
#define MIDI_CMD_CONTROL_CHANGE 0xB0
#define MIDI_CMD_CONTROL_CHANGE_MOD_WHEEL 0x01
#define MIDI_CMD_CONTROL_CHANGE_MOD_SUSTAIN 0x40
#define MIDI_CMD_CONTROL_CHANGE_MOD_VOLUME 0x07
#define MIDI_CMD_CONTROL_CHANGE_MOD_MUTE 0x7B
#define MIDI_CMD_CONTROL_CHANGE_EXPRESSION 0x0B
#define MIDI_CMD_CONTROL_CHANGE_EFFECT_1 0x0C
#define MIDI_CMD_CONTROL_CHANGE_EFFECT_2 0x0D
#define MIDI_CMD_CHANNEL_MODE_MESSAGE 0xB0
#define MIDI_CMD_PROGRAM_CHANGE 0xC0
#define MIDI_CMD_CHANNEL_AFTERTOUCH 0xD0
#define MIDI_CMD_PITCH_BEND 0xE0
#define MIDI_CMD_SYSEX 0xF0
#define MIDI_CMD_TIME_CODE_QTR 0xF1
#define MIDI_CMD_SONG_POSITION 0xF2
#define MIDI_CMD_SONG_SELECT 0xF3
#define MIDI_CMD_CLOCK_TICK 0xF8
#define MIDI_CMD_START 0xFA
#define MIDI_CMD_CONTINUE 0xFB
#define MIDI_CMD_STOP 0xFC
#define MIDI_CMD_RESET 0xFF
#define MIDI_CMD_SYSEX_END 0xF7
#define DEFAULT_LAST_NOTE_VALUE 127
#define MIDI_MIN_NOTE_10V 0
#define MIDI_MAX_NOTE_10V 119
#define MAX_NUM_NOTES_10V 120
#define MIDI_MIN_NOTE_5V 36
#define MIDI_MAX_NOTE_5V 95
#define MAX_NUM_NOTES_5V 60
#define DAC_MAX_OUTPUT_VOLTS 5.0f
#define DAC_OUTPUT_VOLTS_PER_OCTAVE (DAC_MAX_OUTPUT_VOLTS / 5.0f)
#define DAC_OUTPUT_VOLTS_PER_NOTE (DAC_OUTPUT_VOLTS_PER_OCTAVE / 12.0f)
#define MAIN_DAC_7554_SPI_BUS spi0
#define MAIN_DAC_7554_BAUD_RATE 1000000
#define DAC_7554_MAX_RANGE 4096
#define DAC_7554_HALF_SIGNAL 2048
#define DEFAULT_VOLTS_OUTPUT_NOTE_DAC TenVoltOutput
#define DEFAULT_VOLTS_OUTPUT_VELOCITY_DAC TenVoltOutput
#define DEFAULT_VOLTS_OUTPUT_OUT1_DAC TenVoltOutput
#define DEFAULT_VOLTS_OUTPUT_OUT2_DAC TenVoltOutput
#define EX_DAC_7554_SPI_BUS spi1
#define EX_DAC_7554_BAUD_RATE 1000000
#define EX_DAC_7554_MAX_RANGE 4096
#define DEFAULT_VOLTS_OUTPUT_OUTX1_DAC TenVoltOutput
#define DEFAULT_VOLTS_OUTPUT_OUTX2_DAC TenVoltOutput
#define DEFAULT_VOLTS_OUTPUT_OUTX3_DAC TenVoltOutput
#define DEFAULT_VOLTS_OUTPUT_OUTX4_DAC TenVoltOutput
#define DEFAULT_CLOCK_OUT_MAPPING OutputMappingRoute_ClockTick
#define DEFAULT_OUT1_MAPPING OutputMappingRoute_Aftertouch
#define DEFAULT_OUT2_MAPPING OutputMappingRoute_ModWheel
#define DEFAULT_OUTX1_MAPPING OutputMappingRoute_None
#define DEFAULT_OUTX2_MAPPING OutputMappingRoute_None
#define DEFAULT_OUTX3_MAPPING OutputMappingRoute_None
#define DEFAULT_OUTX4_MAPPING OutputMappingRoute_None
#define GeneralFunctionCallback std::function<void()>
#define TimerCallback std::function<void()>
#define OnPinValueChangeCallback std::function<void(uint8_t, bool)>
#define RangeEditorCallback std::function<void(float)>
#define NoValueMidiMessageCallback std::function<void()>
#define SingleValueMidiMessageCallback std::function<void(uint8_t)>
#define DoubleValueMidiMessageCallback std::function<void(uint8_t, uint8_t)>
#define MappedRouteCallback std::function<void(uint16_t, uint16_t)>
#define MappedRouteDataCallback std::function<void(uint16_t)>
#define FxnVoidValueCallback(FXN) [this]() { FXN(); }
#define FxnSingleValueCallback(FXN) [this](auto && PH1) { FXN(std::forward<decltype(PH1)>(PH1)); }
#define FxnDoubleValueCallback(FXN) [this](auto && PH1, auto && PH2) { FXN(std::forward<decltype(PH1)>(PH1), std::forward<decltype(PH2)>(PH2)); }
#define GetTicksMs to_ms_since_boot(get_absolute_time())
enum PinDirection : uint8_t {
    PIN_DIRECTION_OUTPUT = 0,
    PIN_DIRECTION_INPUT = 1
};
enum MonoLcdFramebufferMode : uint8_t {
    LCD_FRAMEBUFFER_MODE_HORIZONTAL = 0,
    LCD_FRAMEBUFFER_MODE_VERTICAL = 1,
    LCD_FRAMEBUFFER_MODE_PAGE = 2,
};
inline void ThrowError(const char *message) {
    throw std::runtime_error(message);
}
typedef struct BoxSize_t {
    int width = 0;
    int height = 0;
} BoxSize;
typedef struct ScreenXYPos_t {
    int xPos = 0;
    int yPos = 0;
} ScreenXYPos;
typedef struct ScreenRectangle_t {
    int xPos = 0;
    int yPos = 0;
    int width = 0;
    int height = 0;
} ScreenRectangle;
typedef struct BitmapImage_t {
    int width = 0;
    int height = 0;
    int bytesWidth = 0;
    int totalBytes = 0;
    uint8_t *data = nullptr;
} BitmapImage;
#define DASHBOARD_VALUE_CHANNEL 0
#define DASHBOARD_VALUE_NOTE 1
#define DASHBOARD_VALUE_VELOCITY 2
#define DASHBOARD_VALUE_OUT2 3
#define DASHBOARD_VALUE_OUT1 4
#define DASHBOARD_VALUE_TRIGGER 5
#define DASHBOARD_VALUE_GATE 6
#define DASHBOARD_VALUE_CLOCK 7
static ScreenXYPos dashboard_value_position[8] = {
    { 14, 0 },
    { 4, 1 },
    {13, 1},
    {4, 2},
    {13, 2},
    {4, 3},
    {9, 3},
    {14, 3}
};
static std::string note_names_display[12] = {
    "C ", "C#", "D ", "D#",
    "E ", "F ", "F#", "G ",
    "G#", "A ", "A#", "B "
};
static int note_image_index[12] = {
    0, 0, 1, 1,
    2, 3, 3, 4,
    4, 5, 5, 6
};
typedef struct RunningState_t {
    volatile uint8_t midiChannel = 0;
    volatile uint8_t currentNote = DEFAULT_LAST_NOTE_VALUE;
    volatile uint8_t currentVelocity = 0;
    volatile uint8_t currentOut1 = 0;
    volatile uint8_t currentOut2 = 0;
    volatile uint8_t currentOutX1 = 0;
    volatile uint8_t currentOutX2 = 0;
    volatile uint8_t currentOutX3 = 0;
    volatile uint8_t currentOutX4 = 0;
    volatile bool triggerState = false;
    volatile bool gateState = false;
    volatile bool clockState = false;
} RunningState;
typedef struct IncomingMidiNoteRange_t {
    int minNoteValue;
    int maxNoteValue;
} IncomingMidiNoteRange;
enum CVOutputVoltsValue : uint8_t {
    TenVoltOutput = 0,
    FiveVoltOutput = 1,
};
enum NotePriorityType : uint8_t {
    NOTE_PRIORITY_LAST = 0,
    NOTE_PRIORITY_HIGHEST = 1,
    NOTE_PRIORITY_LOWEST = 2
};
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

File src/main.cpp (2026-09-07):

/*******************************************************************************
 * Copyright (c) 2026 TechWave Audio (techwaveaudio.com)
 *
 * SPDX-License-Identifier: BSD-3-Clause
 *
 ******************************************************************************/

#include <cmath>
#include <iostream>

#include "Controller.h"
#include "Core0Handler.h"
#include "io/MidiAndOutputHandler.h"
#include "io/MidiController.h"
#include "pico/multicore.h"
#include "pico/stdlib.h"
#include "pico/binary_info/code.h"

/**
 * Global variables
 */

// global system state
SystemState *global_system_state;

// our queues for passing messages across the cores
queue_t signal_queue_core_0_read;
queue_t signal_queue_core_1_read;

// our midi handler
MidiAndOutputHandler *global_midi_output_handler;

// handler for core 0 (display and menu)
Core0Handler *global_core0_handler;

// handler for core 1 (midi and output)
MidiController *global_midi_controller;

/**
 * Debugging pin descriptions
 */
void set_declarations() {
    bi_decl(bi_program_description("TechWave Audio MCM-100"));
    bi_decl(bi_1pin_with_name(ONBOARD_LED_PIN, "onboard LED"));
    bi_decl(bi_1pin_with_name(ENC_LEFT_PIN, "Encoder B"));
    bi_decl(bi_1pin_with_name(ENC_RIGHT_PIN, "Encoder A"));
    bi_decl(bi_1pin_with_name(ENC_BUTTON_PIN, "Encoder button"));
    bi_decl(bi_1pin_with_name(OLED_I2C_DATA_PIN, "OLED I2C Data"));
    bi_decl(bi_1pin_with_name(OLED_I2C_CLOCK_PIN, "OLED I2C Clock"));
    bi_decl(bi_1pin_with_name(DAC_7554_SPI_CLOCK_PIN, "quad 12 bit DAC SPI Clock"));
    bi_decl(bi_1pin_with_name(DAC_7554_SPI_TX_PIN, "quad 12 bit DAC SPI TX"));
    bi_decl(bi_1pin_with_name(DAC_7554_SPI_RX_PIN, "quad 12 bit DAC SPI RX"));
    bi_decl(bi_1pin_with_name(DAC_7554_SPI_CS_PIN, "quad 12 bit DAC SPI CS"));
    bi_decl(bi_1pin_with_name(MIDI_OUT_TX_PIN, "midi out TX"));
    bi_decl(bi_1pin_with_name(MIDI_IN_RX_PIN, "midi in RX"));
    bi_decl(bi_1pin_with_name(PIN_CLOCK_LINE, "clock output"));
    bi_decl(bi_1pin_with_name(PIN_TRIGGER_LINE, "trigger output"));
    bi_decl(bi_1pin_with_name(PIN_GATE_LINE, "gate output"));
    bi_decl(bi_1pin_with_name(PIN_NOTE_LED, "note LED"));
    bi_decl(bi_1pin_with_name(PIN_CLOCK_LED, "clock LED"));
    bi_decl(bi_1pin_with_name(PIN_EX_SPI_CLOCK, "extension DAC SPI clock"));
    bi_decl(bi_1pin_with_name(PIN_EX_SPI_TX, "extension DAC SPI TX"));
    bi_decl(bi_1pin_with_name(PIN_EX_SPI_RX, "extension DAC SPI RC"));
    bi_decl(bi_1pin_with_name(PIN_EX_SPI_CS, "extension DAC SPI CS"));
    bi_decl(bi_1pin_with_name(PIN_EX_SENSE, "extension sense line"));
}

/**
 * Initializes a single GPIO pin
 *
 * @param pinId the pin GPIO number
 * @param direction the pin's direction
 * @param pullUp true to pull up (default false)
 * @param pullDown true to pull down (default false)
 */
void initSetupSinglePin(uint pinId, gpio_dir direction, bool pullUp = false, bool pullDown = false) {
    gpio_init(pinId);

    gpio_set_dir(pinId, direction);
    if (direction == GPIO_IN)
        gpio_set_input_enabled(pinId, true);

    gpio_set_pulls(pinId, pullUp, pullDown);
}

/**
 * Initialize our GPIO pins
 */
void init_all_gpio_pins() {
    initSetupSinglePin(ONBOARD_LED_PIN, GPIO_OUT);

    initSetupSinglePin(ENC_LEFT_PIN, GPIO_IN, true, false);
    initSetupSinglePin(ENC_RIGHT_PIN, GPIO_IN, true, false);
    initSetupSinglePin(ENC_BUTTON_PIN, GPIO_IN);

    initSetupSinglePin(OLED_I2C_DATA_PIN, GPIO_OUT, true, false);
    initSetupSinglePin(OLED_I2C_CLOCK_PIN, GPIO_OUT, true, false);

    initSetupSinglePin(DAC_7554_SPI_CLOCK_PIN, GPIO_OUT);
    initSetupSinglePin(DAC_7554_SPI_TX_PIN, GPIO_OUT);
    initSetupSinglePin(DAC_7554_SPI_RX_PIN, GPIO_IN);
    initSetupSinglePin(DAC_7554_SPI_CS_PIN, GPIO_OUT);

    initSetupSinglePin(MIDI_OUT_TX_PIN, GPIO_OUT);
    initSetupSinglePin(MIDI_IN_RX_PIN, GPIO_IN, true, false);

    initSetupSinglePin(PIN_CLOCK_LINE, GPIO_OUT, false, true);
    initSetupSinglePin(PIN_TRIGGER_LINE, GPIO_OUT, false, true);
    initSetupSinglePin(PIN_GATE_LINE, GPIO_OUT, false, true);

    initSetupSinglePin(PIN_NOTE_LED, GPIO_OUT, false, true);
    initSetupSinglePin(PIN_CLOCK_LED, GPIO_OUT, false, true);

    initSetupSinglePin(PIN_EX_SPI_CLOCK, GPIO_OUT);
    initSetupSinglePin(PIN_EX_SPI_TX, GPIO_OUT);
    initSetupSinglePin(PIN_EX_SPI_RX, GPIO_IN);
    initSetupSinglePin(PIN_EX_SPI_CS, GPIO_OUT);

    initSetupSinglePin(PIN_EX_SENSE, GPIO_IN, true, false);
}

/**
 * Our main program entry point
 *
 * @return (discarded, always 0)
 */
int main() {
    if (get_core_num() != 0) {
        // only run on core 0
        return 0;
    }

    stdio_init_all();
    set_declarations();
    init_all_gpio_pins();

    global_gpio_event_registry_init();

    global_system_state = new SystemState();

    queue_init(&signal_queue_core_0_read, sizeof(SignalMessage_t), MAX_ITEMS_IN_EVENT_QUEUE);
    queue_init(&signal_queue_core_1_read, sizeof(SignalMessage_t), MAX_ITEMS_IN_EVENT_QUEUE);

    global_midi_output_handler = new MidiAndOutputHandler(&signal_queue_core_1_read, &signal_queue_core_0_read);
    global_core0_handler = new Core0Handler(&signal_queue_core_0_read, &signal_queue_core_1_read);
    global_midi_controller = new MidiController(DEFAULT_MIDI_CHANNEL);

    auto controller = new Controller();
    try {
        controller->run();
    } catch (const std::exception& e) {
        std::cerr << e.what() << std::endl;
    }

    global_midi_controller->stop();

    controller->shutdown();

    multicore_reset_core1();

    TimedEventQueue::nonBlockingWait(10);

    delete controller;

    delete global_midi_output_handler;
    delete global_core0_handler;
    delete global_midi_controller;

    queue_free(&signal_queue_core_0_read);
    queue_free(&signal_queue_core_1_read);

    return 0;
}

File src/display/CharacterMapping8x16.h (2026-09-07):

/*******************************************************************************
 * Copyright (c) 2026 TechWave Audio (techwaveaudio.com)
 *
 * SPDX-License-Identifier: BSD-3-Clause
 *
 ******************************************************************************/

#ifndef TECHWAVEAUDIO_MIDI_CONTROLLER_MODULE_CHARACTERMAPPING8X16_H
#define TECHWAVEAUDIO_MIDI_CONTROLLER_MODULE_CHARACTERMAPPING8X16_H
#include <cstdint>

#include "BaseCharacterSet.h"

/**
 * A basic, legible 8x16 mapped character set
 */
class CharacterMapping8x16 : public BaseCharacterSet {
public:
    CharacterMapping8x16();
};

#define CHAR_MAPPING_BYTE_WIDTH_8x16_FONT 8
#define CHAR_MAPPING_BYTE_HEIGHT_8x16_FONT 16
#define CHAR_MAPPING_BYTE_SIZE_8x16_FONT (BASE_CHARACTER_SET_NUM_CHARS_DEFINED * CHAR_MAPPING_BYTE_WIDTH_8x16_FONT * CHAR_MAPPING_BYTE_HEIGHT_8x16_FONT)

static uint8_t char_byte_mapping_8x16[CHAR_MAPPING_BYTE_SIZE_8x16_FONT] = {
    0b00000000,
  0b00000000,
  0b00000000,
  0b00000000,
  0b00000000,
  0b00000000,
  0b00000000,
  0b00000000,
  0b00000000,
  0b00000000,
  0b00000000,
  0b00000000,
  0b00000000,
  0b00000000,
  0b00000000,
  0b00000000,
    0b00000000,
  0b00000000,
  0b00001100,
  0b00001100,
  0b00001100,
  0b00001100,
  0b00001100,
  0b00001100,
  0b00001100,
  0b00000000,
  0b00001100,
  0b00001100,
  0b00000000,
  0b00000000,
  0b00000000,
  0b00000000,
    0b00000000,
  0b00110110,
  0b00110110,
  0b00110110,
  0b00110110,
  0b00110110,
  0b00000000,
  0b00000000,
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
};
#endif // TECHWAVEAUDIO_MIDI_CONTROLLER_MODULE_CHARACTERMAPPING8X16_H

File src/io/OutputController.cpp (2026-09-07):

/*******************************************************************************
 * Copyright (c) 2026 TechWave Audio (techwaveaudio.com)
 *
 * SPDX-License-Identifier: BSD-3-Clause
 *
 ******************************************************************************/

#include "OutputController.h"

#include <cmath>

#include "MidiController.h"
#include "OutputRouteMap.h"
#include "../TechWaveAudio_MidiControllerModule.h"
#include "hardware/gpio.h"

extern MidiController *global_midi_controller;

OutputController::OutputController(SystemState *systemState, TimedEventQueue *eventQueue) {
    _systemState = systemState;
    _eventQueue = eventQueue;
}

OutputController::OutputController(SystemState *systemState, TimedEventQueue *eventQueue,
    MultiCoreController *multiCoreController) {
    _systemState = systemState;
    _eventQueue = eventQueue;
    _multiCoreController = multiCoreController;
}

OutputController::~OutputController() {
    shutdown();
    delete _noteVelOut1Out2Output;
    delete _extensionOutput;
}

void OutputController::init() {
    if (!_isRunning)
        sem_init(&_noteQueueSemaphore, 1, 1);
    else
        sem_reset(&_noteQueueSemaphore, 1);

    _ignoreMidi = true;

    delete _noteVelOut1Out2Output;
    delete _extensionOutput;
    setupHwOutputs();

    _isRunning = true;

    reset();
}

void OutputController::reset() {
    if (!_isRunning)
        return;

    _noteVelOut1Out2Output->writeValue(MAIN_OUT_NOTE_REGISTER, 0);
    _noteVelOut1Out2Output->writeValue(MAIN_OUT_VELOCITY_REGISTER, 0);
    _noteVelOut1Out2Output->writeValue(MAIN_OUT_OUT1_REGISTER, 0);
    _noteVelOut1Out2Output->writeValue(MAIN_OUT_OUT2_REGISTER, 0);

    if (_systemState->expansionSensed) {
        _extensionOutput->writeValue(EXT_OUT_X1_REGISTER, 0);
        _extensionOutput->writeValue(EXT_OUT_X2_REGISTER, 0);
        _extensionOutput->writeValue(EXT_OUT_X3_REGISTER, 0);
        _extensionOutput->writeValue(EXT_OUT_X4_REGISTER, 0);
    }

    gpio_put(PIN_CLOCK_LINE, false);
    gpio_put(PIN_TRIGGER_LINE, false);
    gpio_put(PIN_GATE_LINE, false);

    if (global_midi_controller == nullptr) {
        throw std::exception();
    }

    setPitchBendRangeChanged();

    global_midi_controller->stop();

    _mappingRoute = new OutputRouteMap();
    updateMappingRoutes();

    _sustainValue = false;

    global_midi_controller->setOnResetCallback([this] { onResetCallback(); });
    global_midi_controller->setOnClockCallback([this] { onClockCallback(); });
    global_midi_controller->setOnAllNotesOffCallback([this] { allNotesOffCallback(); });
    global_midi_controller->setOnStartCallback([this] { onStartCallback(); });
    global_midi_controller->setOnStopCallback([this] { onStopCallback(); });

    global_midi_controller->setOnModWheelCallback([this](uint8_t data) { onModWheelCallback(data); });
    global_midi_controller->setOnSustainCallback([this](uint8_t data) { onSustainCallback(data); });
    global_midi_controller->setOnVolumeChangedCallback([this](uint8_t data) { onVolumeCallback(data); });
    global_midi_controller->setOnAftertouchCallback([this](uint8_t data) { onAftertouchCallback(data); });

    global_midi_controller->setOnNoteOnCallback([this](uint8_t note, uint8_t velocity) { noteOnCallback(note, velocity); });
    global_midi_controller->setOnNoteOffCallback([this](uint8_t note, uint8_t velocity) { noteOffCallback(note, velocity); });
    global_midi_controller->setOnPitchBendCallback([this](uint8_t highByte, uint8_t lowByte) { onPitchBendCallback(highByte, lowByte); });

    TimedEventQueue::nonBlockingWait(500);

    _ignoreMidi = false;
    global_midi_controller->start();

    _currentState.midiChannel = _systemState->midiChannel;
}

void OutputController::shutdown() {
    if (!_isRunning)
        return;

    _isRunning = false;

    global_midi_controller->stop();

    clearNoteQueue();

    _noteVelOut1Out2Output->writeValue(MAIN_OUT_NOTE_REGISTER, 0);
    _noteVelOut1Out2Output->writeValue(MAIN_OUT_VELOCITY_REGISTER, 0);
    _noteVelOut1Out2Output->writeValue(MAIN_OUT_OUT1_REGISTER, 0);
    _noteVelOut1Out2Output->writeValue(MAIN_OUT_OUT2_REGISTER, 0);
    gpio_put(PIN_CLOCK_LINE, false);
    gpio_put(PIN_TRIGGER_LINE, false);
    gpio_put(PIN_GATE_LINE, false);

    if (_systemState->expansionSensed) {
        _extensionOutput->writeValue(EXT_OUT_X1_REGISTER, 0);
        _extensionOutput->writeValue(EXT_OUT_X2_REGISTER, 0);
        _extensionOutput->writeValue(EXT_OUT_X3_REGISTER, 0);
        _extensionOutput->writeValue(EXT_OUT_X4_REGISTER, 0);
    }

    delete _mappingRoute;
    _mappingRoute = nullptr;
    sem_reset(&_noteQueueSemaphore, 1);
}

void OutputController::updateMappingRoutes() {
    // clear any existing event callbacks for outputs
    _eventQueue->removeCallbackEvent(_out2OutputQueueId);
    _eventQueue->removeCallbackEvent(_out1OutputQueueId);
    _eventQueue->removeCallbackEvent(_clockCallbackQueueId);

    std::vector<OutputMappingRouteItem> newRoutes;

    newRoutes.push_back({_systemState->out1Mapping, OutputMappingOutput_Out1});
    newRoutes.push_back({_systemState->out2Mapping, OutputMappingOutput_Out2});
    newRoutes.push_back({_systemState->clockOutputMapping, OutputMappingOutput_Clock});
    if (_systemState->expansionSensed) {
        newRoutes.push_back({_systemState->outX1Mapping, OutputMappingOutput_OutX1});
        newRoutes.push_back({_systemState->outX2Mapping, OutputMappingOutput_OutX2});
        newRoutes.push_back({_systemState->outX3Mapping, OutputMappingOutput_OutX3});
        newRoutes.push_back({_systemState->outX4Mapping, OutputMappingOutput_OutX4});
    }

    if (_systemState->out1Mapping != _lastOut1Route)
        writeOut1Data(0);
    if (_systemState->out2Mapping != _lastOut2Route)
        writeOut2Data(0);
    if (_systemState->clockOutputMapping != _lastClockRoute) {
        gpio_put(PIN_CLOCK_LINE, false);
        gpio_put(PIN_CLOCK_LED, false);
    }

    _lastOut1Route = _systemState->out1Mapping;
    _lastOut2Route = _systemState->out2Mapping;
    _lastClockRoute = _systemState->clockOutputMapping;

    if (_systemState->expansionSensed) {
        if (_systemState->outX1Mapping != _lastOutX1Route)
            writeOutX1Data(0);
        if (_systemState->outX2Mapping != _lastOutX2Route)
            writeOutX2Data(0);
        if (_systemState->outX3Mapping != _lastOutX3Route)
            writeOutX3Data(0);
        if (_systemState->outX4Mapping != _lastOutX4Route)
            writeOutX4Data(0);

        _lastOutX1Route = _systemState->outX1Mapping;
        _lastOutX2Route = _systemState->outX2Mapping;
        _lastOutX3Route = _systemState->outX3Mapping;
        _lastOutX4Route = _systemState->outX4Mapping;
    }

    _mappingRoute->updateRoutes(newRoutes);
}

void OutputController::processMidiQueue() {
    if (global_midi_controller != nullptr) {
        while (global_midi_controller->processMidiQueue()) {
            tight_loop_contents();
        }
    }
}
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

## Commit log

2026-06-23 working production hardware
    [TechWaveAudio_MidiController.kicad_pcb]
2026-06-23 correct i2c / spi
    [TechWaveAudio_MidiController.kicad_pcb]
2026-06-23 working multicore
    [TechWaveAudio_MidiController.kicad_pcb, TechWaveAudio_MidiController.kicad_sch]
2026-06-24 PCB update; cleanups
    [TechWaveAudio_MidiController.kicad_pcb, TechWaveAudio_MidiController.kicad_sch]
2026-06-26 doc cleanups and add images
    [TechWaveAudio_MidiController.kicad_pcb, TechWaveAudio_MidiController.kicad_sch]
2026-06-27 safe flash i/o; cleanups; multicore fixes
    [Controller.cpp, MidiController.cpp]
2026-06-27 correct pitch bend range output
    [Controller.cpp, OutputController.cpp]
2026-06-28 fix error in ctl/aux output
    [OutputController.cpp]
2026-06-28 update pcb; move LEDs and mounting
    [TechWaveAudio_MidiController.kicad_pcb]
2026-06-30 hardware docs; cleanups and comments
    [TechWaveAudio_MidiController.kicad_pcb, TechWaveAudio_MidiController.kicad_sch]
2026-06-30 parts list; update board
    [TechWaveAudio_MidiController.kicad_sch, TechWaveAudio_MidiController_BOM.csv]
2026-07-01 board update
    [TechWaveAudio_MidiController.kicad_pcb]
2026-07-09 latest board design
    [TechWaveAudio_MidiController.kicad_pcb, TechWaveAudio_MidiController.kicad_sch]
2026-07-10 add tip support image/link
    [TechWaveAudio_MidiController.kicad_pcb]
2026-07-15 working USB midi device support
2026-07-15 move PCB and panel to separate folders
    [TechWaveAudio_MidiController.kicad_pcb, TechWaveAudio_MidiController.kicad_sch]
2026-07-16 add gerbers, update README
    [TechWaveAudio_MidiController.kicad_pcb]
2026-07-19 light cleanups
    [TechWaveAudio_MidiController.kicad_pcb]
2026-07-19 update BOM
    [TechWaveAudio_MidiController_BOM.csv]
2026-07-30 fix routed outputs; add routes; new calibration menu;
    [Controller.cpp, GpioPinEventHandler.cpp, OutputController.cpp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]
2026-08-01 multi-note queue; stability updates
    [OutputController.cpp, OutputController.h]
2026-08-04 fix +5v ctl/aux signal output
    [OutputController.cpp]
2026-09-07 updates for v 2.0.0 (#3)
    * use quad DAC / rotary encoder
    * cleanups and refactoring
    * updaed new menu system w/ ext
    * add ex outputs to hw controller
    * run testing / calbibration on startup
    * working hardware; outputs
    * cleanups and refactoring
    * hardware design updates for 2.0.0
    * set extension sense
    * update expansion; ensure ex state is properly set
    * better 7554 ; spi; i2c control; test all outputs selection
    * update dashboard display for extension output
    * better responsiveness; fix crashes; midi command queue
    * fix ex sense; fix clock led menu
    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
    [RotaryEncoderCarrierBoard.kicad_pcb, RotaryEncoderCarrierBoard.kicad_sch, TechWaveAudio-MCM-100-EX.kicad_pcb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]
